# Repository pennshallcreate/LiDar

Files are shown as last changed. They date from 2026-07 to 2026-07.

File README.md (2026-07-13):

# LiDar — a budget DIY 360° 3D LiDAR scanner

A buildable, portable, USB-C-rechargeable 360° 3D scanner modeled on the
open-source [PiLiDAR](https://github.com/PiLiDAR/PiLiDAR) project: an
LDRobot 2D LiDAR spun on a stepper-driven turntable, orchestrated by a
Raspberry Pi 3 Model A+, exporting colored PLY point clouds. No camera, no panorama
stitching — just the scanning core, built to a real budget.

| | |
|---|---|
| **Cost** | $188 all-new, or $158 if you already own the Pi 3 A+ — see the budget note in [BOM.md](BOM.md) |
| **Compute** | Raspberry Pi 3 Model A+ (factory-soldered 40-pin header, dual-band Wi-Fi) |
| **Sourcing** | 100% Amazon, Prime-eligible — see [Parts.md](Parts.md) for the plain shopping list |
| **Build skill** | No soldering, no multimeter — breadboard + push-fit connectors throughout |
| **Sensor** | LDRobot LD19 (or LD06), 4500 samples/s, 0.02–12m range |
| **Runtime** | ≥2.5h worst-case, ~5.5h typical, on a single USB-C power bank charge — [proof](ARCHITECTURE.md#5-power-budget) |
| **Output** | Binary PLY point clouds, intensity-colored |
| **License** | [CC BY-NC-SA 4.0](LICENSE.md) (inherited from PiLiDAR) |

## Documentation

1. **[BOM.md](BOM.md)** — parts list, current prices, sourcing, and the
   no-solder/no-multimeter design constraints this build is built around
   (**[Parts.md](Parts.md)** has just the shopping list, no explanation)
2. **[ARCHITECTURE.md](ARCHITECTURE.md)** — wiring/pinout, motion system,
   and the power budget proving the runtime requirement
3. **[`src/`](src/)** — Python: LiDAR serial capture, stepper control,
   point-cloud assembly, PLY export, calibration
4. **[PRINTS.md](PRINTS.md)** — 3D-printed parts, dimensions, and
   parametric OpenSCAD source in [`models/`](models/)
5. **[BUILD.md](BUILD.md)** — ordered assembly and test checklist, start
   to first scan

If you're building one of these, read them in that order. If you just want
to know whether this is worth building: it's a real, working scanner for
about the price of a mid-range LiDAR sensor alone, with the tradeoffs
(anisotropic resolution, a blind cone underneath, no RGB by default)
documented rather than glossed over — see ARCHITECTURE.md's limitations
section before committing to a parts order.

## Credit

This project adapts code, wiring conventions, and the overall scan
geometry from [PiLiDAR](https://github.com/PiLiDAR/PiLiDAR) and
[PiLiDAR-Hardware](https://github.com/PiLiDAR/PiLiDAR-Hardware) by Philip
Gutjahr, CC BY-NC-SA 4.0. See [LICENSE.md](LICENSE.md) for the full
attribution and what's original vs. adapted.

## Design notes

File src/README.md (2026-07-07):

# src/

Onboard Python for the scanner (runs on the Pi itself, headless). Hardware
context is in [../ARCHITECTURE.md](../ARCHITECTURE.md); assembly and the
first-scan checklist is in [../BUILD.md](../BUILD.md) -- start there if
you're setting one of these up. This file is just a map of the code.

## Setup

```bash
python3 -m venv venv
source venv/bin/activate
pip install -r requirements.txt
```

Edit `config.json` first: set `STEPPER.DRIVER` to `"A4988"` or `"ULN2003"`
to match your build tier (BOM.md), and `LIDAR.DEVICE` to `"LD19"` or
`"LD06"`.

## Files

| File | Role |
|---|---|
| `config.json` / `config.py` | Central config: device selection, pins, scan geometry, offsets. Everything else reads from here. |
| `crc_table.json` | CRC8 lookup table for the LD06/LD19 UART protocol. |
| `lidar_driver.py` | Serial capture: reads packets, checks CRC8, decodes angle/distance/intensity, controls motor-speed PWM. |
| `stepper_driver.py` | Turntable motor control -- `A4988` (NEMA17) and `ULN2003` (28BYJ-48) classes behind one interface; `Stepper(config)` picks the right one. |
| `pointcloud.py` | 2D-per-revolution -> merged 3D point cloud, intensity colorization, binary/ASCII PLY export. Pure NumPy, no Open3D (see ARCHITECTURE.md § 2). |
| `scan.py` | Main entry point: runs a full scan and writes the PLY. `python3 scan.py --help` for options. |
| `calibrate_pwm.py` | One-time motor speed-vs-PWM calibration (produces `PWM_COEFFS` for config.json). |
| `calibrate_mechanical.py` | Fast, low-res scan for iterating on the mechanical offset constants (`Y_OFFSET`/`Z_OFFSET`/`LIDAR_OFFSET_ANGLE`). |
| `imu_driver.py` | Optional MPU6050 tilt sensor, only used if `ENABLE_IMU: true`. |
| `button_daemon.py` | Scan-trigger button listener, meant to run as a systemd service (BUILD.md). |
| `platform_utils.py` / `file_utils.py` | Small shared helpers (serial/PWM init, directory helpers). |

## Running a scan manually

```bash
python3 scan.py
```

Output goes to `scans/<timestamp>/`: the raw per-revolution pickle
(`*_lidar.pkl`) and the exported point cloud (`*.ply`).

## Attribution

Several files here are adapted from [PiLiDAR](https://github.com/PiLiDAR/PiLiDAR)
(c) Philip Gutjahr, licensed CC BY-NC-SA 4.0 -- see the per-file header
comments for which ones, and [../LICENSE.md](../LICENSE.md) for the full
license text this repository is released under as a result.

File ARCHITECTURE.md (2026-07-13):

# Architecture

System design, wiring/pinout, and the power budget proving ≥15 minutes of
continuous scan runtime. Parts referenced here are defined in
[BOM.md](BOM.md); assembly order is in [BUILD.md](BUILD.md); printed-part
geometry is in [PRINTS.md](PRINTS.md).

## 1. System overview

Like PiLiDAR, this is a **2D LiDAR spun on two axes** rather than a native 3D
LiDAR: the sensor's own motor sweeps a vertical circle at ~10 Hz, and a
stepper-driven turntable slowly sweeps that vertical circle through 180° of
azimuth over the course of a scan. The two sweeps together cover a full
sphere.

```
                         ┌───────────────┐
                         │   LD19 LiDAR   │  spins its own beam
                         │  (vertical     │  in a vertical circle
                         │   plane)       │  @ ~10 Hz
                         └───────┬───────┘
                                 │ mast
                         ┌───────┴───────┐
                         │   platter      │  rotated by a 28BYJ-48
                         │ (lazy-susan    │  through 180° over the scan
                         │  bearing)      │
                         └───────┬───────┘
                                 │
        ┌────────────────────────────────────────────┐
        │  base: Pi 3 A+, breadboard + ULN2003        │
        │  driver, buttons -- single 5V rail, no      │
        │  boost converter needed (§4.1)              │
        └────────────────────────────────────────────┘
                                 │
                         USB-C power bank
```

**Why 180°, not 360°, of turntable rotation:** one full revolution of the
LiDAR's own spin already sweeps a plane that passes through the mast axis —
i.e. it looks "forward" and "backward" (180° apart) *simultaneously*, once
per revolution. Stepping the turntable through a full 180° therefore already
sweeps that plane through every possible azimuth exactly once; going to 360°
would just re-scan the same sphere a second time. This is exactly the
geometry PiLiDAR uses (`SCAN_ANGLE: 180` in its config) and it halves scan
time for free.

**Resolution:** vertical (elevation) resolution is fixed by the LiDAR's own
sampling rate and spin speed (4500 samples/s ÷ ~10 rev/s ≈ 450 points/rev ≈
0.8°/point, native). Azimuth resolution is set by how finely the turntable
steps — see [§4](#4-motion-system) — and is comfortably finer than 0.8°, so
elevation, not azimuth, is the resolution bottleneck, same as the reference
project.

## 2. Compute: Raspberry Pi 3 Model A+

A Pi 4 (PiLiDAR's choice) is massive overkill for a LiDAR-only build with no
camera/panorama/meshing pipeline running on-device — that pipeline is the
part PiLiDAR uses the extra RAM/CPU for, and it's exactly the part we've cut.
What's left (read UART, toggle GPIO, buffer numpy arrays, write a PLY file)
comfortably fits the 3 A+'s quad-core Cortex-A53 @ 1.4 GHz and 512 MB RAM,
at well under half the Pi 4's price and power draw. The 40-pin header,
hardware PWM, and mini-UART are all identical to the Pi 4 for our purposes,
so PiLiDAR's GPIO-level driver code ports over almost unchanged (see
`src/`). Two 3 A+ perks this build actively uses: the header ships
**pre-soldered as standard** (load-bearing for the no-soldering constraint —
see BOM.md), and its dual-band 802.11ac Wi-Fi makes headless scan pull-off
faster and more reliable than a 2.4 GHz-only board in a congested
apartment-Wi-Fi environment. The full-size USB-A and HDMI ports go unused
during scanning, but they make bench debugging (keyboard, monitor, USB
serial adapter) possible without any adapters — something a Pi Zero-class
board can't offer.

**Deliberate simplification vs. PiLiDAR:** the onboard code never imports
Open3D. Point-cloud assembly is plain NumPy (coordinate transforms over a
few hundred thousand points — seconds, not minutes, on this CPU) and PLY
export is a ~30-line manual binary writer (`src/pointcloud.py`). Open3D is a
large, native-compiled dependency; avoiding it on a 512 MB board sidesteps a
real memory/build-time risk for zero loss of the required output (binary
PLY). If you want Open3D-powered visualization, ICP registration, or Poisson
meshing, PiLiDAR already documents that workflow well — run it on a laptop
against the PLY this device produces, exactly as PiLiDAR itself recommends
doing for the slow steps ("Poisson Surface Meshing... recommended to run on
PC").

## 3. GPIO pinout

All pin numbers are **BCM numbering**, all connections are push-fit Dupont
jumpers into the Pi 3 A+'s pre-soldered 40-pin header (soldered at the
factory on every 3 A+ — no soldering anywhere, see BOM.md) routed through a
breadboard. This map is carried
over from PiLiDAR unchanged where the subsystem is unchanged (LiDAR
UART/PWM, buttons) — no reason to diverge from a proven pin assignment.

| Signal | Pi GPIO (BCM) | Physical pin | Notes |
|---|---|---|---|
| LiDAR UART RX | GPIO15 (RXD0) | 10 | mini-UART (`/dev/ttyS0`); LiDAR only transmits, so TX (GPIO14) is unused. On the 3 A+ (a Bluetooth-equipped Pi) the mini-UART is disabled by default — `enable_uart=1` in `config.txt` turns it on and pins the core clock so the baud rate stays stable (BUILD.md Phase 4) |
| LiDAR motor speed (PWM) | GPIO18 (PWM0) | 12 | hardware PWM, `rpi-hardware-pwm` |
| Scan-trigger button | GPIO17 | 11 | to GND, internal pull-up, falling-edge |
| Power button | GPIO3 | 5 | hardwired wake pin; `dtoverlay=gpio-shutdown` |
| ULN2003 IN1 | GPIO26 | 37 | default build's stepper driver — see §4.1 |
| ULN2003 IN2 | GPIO19 | 35 | |
| ULN2003 IN3 | GPIO5 | 29 | |
| ULN2003 IN4 | GPIO6 | 31 | |
| IMU SDA (optional) | GPIO22 | 15 | `i2c-gpio` bus 3 — GPIO2/3 (hw I2C) are unavailable, GPIO3 is the power button |
| IMU SCL (optional) | GPIO27 | 13 | `i2c-gpio` bus 3 |
| 5V (LiDAR VCC, ULN2003 VCC, Pi power in) | 5V pins | 2, 4 | single rail — see §4.1, no boost converter in the default build |
| GND (common) | GND | 6, 9, 14, 20, 25, 30, 34, 39 | tie LiDAR GND, ULN2003 GND, button GND all to Pi GND |

**If you upgrade to the optional NEMA17 + A4988 path** (§4.2 — needs a
multimeter, not part of the default build): it reuses GPIO26/19 as
DIR/STEP, adds GPIO5/6/13 as MS1/MS2/MS3, GPIO13 (physical pin 33) being
the only pin the default ULN2003 build leaves unused. It also adds its own
3.3V (driver logic VDD, pin 1 or 17) and a boost-converter GND to the
common ground.

## 4. Motion system

### 4.1 Default build: 28BYJ-48 + ULN2003 (no multimeter, no soldering)

This is the build BUILD.md walks through. The ULN2003 board just switches
4 GPIO outputs to the motor's 4 coils in sequence (`src/stepper_driver.py`'s
`ULN2003` class) — there's no current limit to set and nothing to measure,
unlike a bipolar driver. It runs natively at 5V, so **the whole build is a
single 5V rail**: battery → Pi → (Pi's own 5V GPIO pins) → LiDAR + ULN2003.
No boost converter anywhere.

- **Direct drive, no gearbox.** Same reasoning as PiLiDAR's geared design,
  simplified: the 28BYJ-48's own internal ~64:1 gearbox already gives
  ~4096 steps/rev = 0.088°/step at its output shaft — finer than the
  LiDAR's native ~0.8° vertical resolution — and has enough torque for a
  few-hundred-gram printed mast without any additional external gearing.
  See [PRINTS.md](PRINTS.md) for the mechanical layout.
- **The lazy-susan bearing carries the load, not the motor shaft** — the
  platter sits on the hardware bearing; the motor connects via a printed
  hub that only has to transmit torque, keeping side-load off the motor's
  small internal bearings.
- **The motor's cable plugs directly into the ULN2003 board's onboard
  socket** — no crimping, no soldering, it's sold as a matched pair.
- **Torque/speed margin is real but smaller than a NEMA17's** (roughly
  1/10th the holding torque) — see [BOM.md](BOM.md#optional-upgrades-not-included-in-the-188-total)
  for when that matters and the NEMA17 upgrade path below.

### 4.2 Optional upgrade: NEMA17 + A4988 (needs a multimeter)

Not part of the default build — described here for when/if you pick up a
multimeter and want more torque/speed margin. `src/stepper_driver.py`'s
`A4988` class and `models/motor_hub_nema17.scad` already support it; set
`STEPPER.DRIVER` to `"A4988"` in `config.json` to switch.

- **Direct drive, no gearbox.** At 16× microstepping a NEMA17 alone gives
  3200 microsteps/rev = 0.1125°/step, finer than the LiDAR's native ~0.8°
  resolution, with roughly 10× the torque this load needs even ungeared —
  no need for PiLiDAR's 3D-printed planetary reduction.
- **Microstep truth table** (MS1/MS2/MS3 → resolution), standard A4988:

  | MS1 | MS2 | MS3 | Microsteps |
  |---|---|---|---|
  | Low | Low | Low | 1 (full step) |
  | High | Low | Low | 2 |
  | Low | High | Low | 4 |
  | High | High | Low | 8 |
  | High | High | High | 16 ← used |

- **Current limit (Vref) — this is the step that needs a multimeter.** Set
  the driver's onboard trimpot for **0.5 A/phase** — comfortable torque
  margin for this load without wasting battery power as heat. Formula for
  the common 0.05 Ω sense-resistor A4988 breakout (verify your board's
  sense resistor against its silkscreen/datasheet before trusting this
  number): `I_limit = V_ref × 2.5`, so `V_ref = I_limit / 2.5 = 0.2 V`.
  Measure with a multimeter between the trimpot wiper and GND, motor
  **disconnected**, before wiring it up. Get this wrong and you either
  stall the motor (limit too low) or overheat the driver (limit too high) —
  this is precisely the failure mode the default ULN2003 build has no
  equivalent of.
- **SLEEP/RESET/ENABLE.** Bridge `SLEEP` to `RESET` with a short jumper
  directly on the driver board, tie that joined pair to the driver's logic
  `VDD` (3.3V), and tie `ENABLE` (active-low) straight to `GND`.
- **VMOT (motor power) — the other multimeter step.** 12V from a boost
  converter (e.g. MT3608, 5V→12V), trimmed with its onboard pot and
  **verified with a multimeter before connecting the driver** — cheap
  boost modules can ship set to their maximum (sometimes 28V+). **Never
  run VMOT below ~8V** — the A4988's internal charge pump needs it, and
  the driver can behave unreliably below that, which is why this path
  needs a boost converter at all rather than feeding the driver straight
  off the 5V battery rail.

## 5. Power budget

**Requirement: ≥15 minutes of continuous operation with the LiDAR, stepper,
and Pi all active simultaneously (the actual worst case during a scan).**

This is for the default build: Pi + LiDAR + 28BYJ-48/ULN2003, all off one
5V rail, 10,000 mAh power bank (BOM.md). No boost converter in the loop —
one less conversion-efficiency loss to account for.

### Worst-case bound (the proof)

Deliberately pessimistic on every number, so this is a floor, not an
expectation:

| Load | Draw |
|---|---|
| Pi 3 A+ (CPU+Wi-Fi, pessimistic ceiling — measured stress figures run 0.7–0.85 A, this rounds up) | 1.00 A @ 5V = 5.00 W |
| LD19 LiDAR (datasheet current, upper end) | 0.45 A @ 5V = 2.25 W |
| 28BYJ-48/ULN2003 (datasheet worst-case combined coil current) | 0.40 A @ 5V = 2.00 W |
| **Total draw** | **9.25 W** (≈1.85 A @ 5V) |

That 1.85 A worst-case total also clears the power bank's output rating
with room to spare (typical 10,000 mAh banks deliver 2.4–3 A per port) —
use the bank's highest-rated output port, since the 3 A+'s official
recommended supply is 2.5 A.

| | |
|---|---|
| Nominal energy (10 Ah × 3.7 V) | 37.0 Wh |
| × 80% (aged-battery/cold derating) | 29.6 Wh |
| × 80% (USB boost conversion, low end — this is the power bank's own internal 3.7V-cell-to-5V-output conversion, not an external boost converter) | **23.68 Wh usable** |
| ÷ worst-case draw | 23.68 / 9.25 W |
| **Runtime floor** | **153 min (2h 33m)** |
| **Margin over the 15-min requirement** | **10.2×** |

### Typical case (practical expectation)

Real (lighter) stepper draw, fresh battery, mixed CPU/Wi-Fi load:

| | |
|---|---|
| Total typical draw | ≈6.0 W |
| Usable energy (100% capacity × 88% conversion) | 32.6 Wh |
| **Typical runtime** | **≈5h 26m** |

In practice, expect a full day of scanning (dozens of individual scans at
~1.5–2 min each, see §6) per charge, not a single 15-minute window — the
10× worst-case margin is that generous mostly because dropping the boost
converter (§4.1) removed both a conversion-efficiency loss and a
several-watt load at the same time. (The move from a Pi Zero 2 W to the
3 A+ in this revision cost roughly an hour of worst-case floor — 210 min
down to 153 min — a fair trade for the faster CPU clock, dual-band Wi-Fi,
and factory-soldered header, and still 10× more runtime than required.)

### If you add the optional NEMA17 + A4988 upgrade (§4.2)

That path reintroduces a boost converter and a heavier motor load — budget
roughly 12-15W for the stepper+driver+boost stage (current-limited to
0.5A/phase, ~80% boost efficiency) instead of the 2W above. Total draw
becomes ≈19.5-22.5W worst case, which against the same 23.68Wh usable
energy still clears the 15-minute requirement (≈63-73 min floor, 4.2-4.9×
margin) — just with noticeably less margin than the default build, and
only worth doing once you have the multimeter that path requires anyway.

## 6. Scan duration (informational, not a hard requirement)

At the default resolution (`TARGET_RES: 0.225`, which the 28BYJ-48's 4096
steps/rev turns into 682 steps of ~0.264°/step over the 180° sweep) the
LiDAR itself is the pacing element: 4500 samples/s ÷ 12 samples/package =
375 packages/s, and the scan needs
`682 steps × ~38 packages/step ≈ 25,900 packages`, i.e. **≈69 seconds** per
full 360°×180° scan. Tunable via `TARGET_RES` in `config.json`, exactly
like PiLiDAR. (The optional NEMA17 upgrade's finer 3200 steps/rev would
give ~0.1125°/step and a correspondingly longer scan at the same
`TARGET_RES` — `python3 config.py` prints the actual numbers for whatever
`config.json` currently has configured.)

## 7. Data flow

```
LD19 (UART, 230400 baud) ──▶ lidar_driver.py ──▶ raw scan buffer (numpy, per-revolution)
                                                          │
stepper_driver.py ◀── scan.py orchestrates ──────────────┤
   (steps once per revolution, records current angle)     │
                                                          ▼
                                          pointcloud.py: revolve each
                                          2D revolution by its recorded
                                          azimuth angle → merged XYZI
                                                          │
                                                          ▼
                                        intensity → viridis colormap
                                                          │
                                                          ▼
                                            binary PLY written to
                                            /scans/<timestamp>/scan.ply
```

Raw per-revolution data is also pickled to disk (`<timestamp>_lidar.pkl`,
same format as PiLiDAR) before merging, so a scan is never lost to a
crash in the merge/export step and can be re-processed later with different
offsets.

## 8. Known limitations (inherent to this scan geometry, not this budget)

- **Blind cone directly below the device.** The base/platter physically
  blocks the LiDAR's view of the ground directly underneath it — identical
  limitation to PiLiDAR and to every mast-mounted spinning-LiDAR scanner.
  Elevate the scanner (tripod, see [BUILD.md](BUILD.md)) if you need
  near-field floor coverage.
- **Anisotropic resolution.** Azimuth resolution (fine, stepper-controlled)
  and elevation resolution (coarser, fixed by the LiDAR's own spin speed)
  are not equal — same as PiLiDAR. This is a property of the "2D LiDAR on
  two axes" approach, not something a bigger budget fixes without a
  different sensor architecture entirely (e.g. a solid-state 3D LiDAR, which
  is a different price class altogether).
- **No RGB by default.** See BOM.md's optional-upgrades section.

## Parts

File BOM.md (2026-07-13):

# Bill of Materials

This scanner is a budget-hardware remix of [PiLiDAR](https://github.com/PiLiDAR/PiLiDAR)
(Raspberry Pi + LDRobot 2D LiDAR + stepper turntable → 3D point cloud). The HQ
camera / panorama-texturing half of PiLiDAR is dropped entirely — this is a
LiDAR-only scanner that exports intensity-shaded PLY point clouds.

**Builder constraints this BOM is designed around: no soldering, no
multimeter, every part on Amazon, compute fixed at a Raspberry Pi 3 Model
A+.** Every connection below
is push-fit (breadboard + Dupont jumpers + plug-in connectors) and nothing
requires measuring a voltage or current to set up — see
[the no-solder/no-multimeter design section](#design-for-no-soldering-and-no-multimeter)
for what that changed from a typical stepper-driven build. See
[Parts.md](Parts.md) for just the shopping list with no explanation.

## TL;DR

| | |
|---|---|
| **Total** | **$188 buying everything new** — or **$158 if you already own the Pi 3 A+** (see [the budget note](#the-175-cap-and-the-pi-3-a)) |
| Sourcing | 100% Amazon, Prime-eligible |
| Turntable drive | 28BYJ-48 + ULN2003 — plug-in connector, no current-limit tuning, no multimeter |
| Wiring | Solderless breadboard + Dupont jumpers throughout |
| Battery runtime, worst case / typical | see [ARCHITECTURE.md § Power budget](ARCHITECTURE.md#5-power-budget) |

## Design for no soldering and no multimeter

The stepper-driven-turntable design pattern most DIY LiDAR scanners
(including PiLiDAR itself) use is built around a NEMA17 + A4988 driver,
which needs two things this BOM specifically avoids:

1. **A4988's current limit is set with a trimpot, measured with a
   multimeter** (a wrong-by-a-lot setting can overheat the driver or
   stall the motor). No multimeter, no safe way to set it.
2. **NEMA17 needs 9-12V**, which means a boost converter between the 5V
   battery and the driver — another component whose output voltage you
   trim and verify with a multimeter before it's safe to connect to
   anything.

Both are gone from this build. Instead:

- **Motor: 28BYJ-48 + ULN2003**, not NEMA17 + A4988. The ULN2003 board
  just switches 4 GPIO signals to the motor coils directly — there's no
  current limit to set, nothing to measure, nothing to trim. It runs
  natively at 5V, so **the boost converter disappears too** — everything
  in this build (Pi, LiDAR, motor) runs off one 5V rail. This does trade
  away some torque/speed margin vs. a NEMA17 — see
  [ARCHITECTURE.md § 4](ARCHITECTURE.md#4-motion-system) for why that's a
  fine tradeoff at this load, and how to upgrade later if you ever do pick
  up a multimeter.
- **Wiring: a solderless breadboard + Dupont jumper wires**, not perfboard.
  The Pi 3 A+'s 40-pin header comes soldered from the factory (every 3 A+
  ships that way — no "WH vs W" variant trap to dodge) and takes push-on
  female Dupont wires directly — no soldering iron touches anything in
  this build. The LiDAR module's cable and the ULN2003-to-28BYJ48 connector are
  both pre-terminated plug-in connectors out of the box (see the LiDAR
  line item below for the one thing to double check when it arrives).
- **No voltage/current measurement anywhere in the build.** BUILD.md's
  power-on checklist is entirely "does it visibly move / does it print a
  reading" checks, not multimeter readings.

## Everything on Amazon

Every part below is sourced on Amazon, Prime-eligible — the whole BOM
should ship free in 1-2 days, likely in one or two boxes. This trades
away the cheaper overseas LiDAR sourcing (~$67 via a China-based reseller
like sunsky-online, 1-3 week shipping, no easy returns) for Prime speed
and Amazon's return policy — worth it on its own for the LiDAR
specifically, since a DOA sensor is much harder to diagnose without a
multimeter, and much easier to just exchange.

## Parts list — $188 ($158 without the Pi)

| Part | Price | Source | Notes |
|---|---|---|---|
| **LDRobot LD19 LiDAR** ("D300" kit: sensor + cable) | **$90** | [Amazon: WayPonDEV FHL-LD19](https://www.amazon.com/DTOF-D300-Distance-Obstacle-Education/dp/B0B1V8D36H) (also sold as [Waveshare D300](https://www.amazon.com/Waveshare-DTOF-LIDAR-LD19-Omni-Directional/dp/B0B3RWKJ1P) — compare current prices, these fluctuate more than most Amazon listings, seen $90-170) | 4500 samples/s, 0.02–12 m, 5V UART+PWM. **Check the product photos before ordering**: you want a cable ending in loose/Dupont-style female connector pins (the standard way these wire to a Pi, no tool needed). If yours instead ends in a bare-wire or unfamiliar connector, search Amazon for a small "JST to Dupont adapter cable" (~$7) — not included in the total above since most listings don't need it. LD06 is a drop-in alternative the code already supports. |
| **Raspberry Pi 3 Model A+** | **$30** (MSRP is $25; Amazon street price runs $28–35 — skip this line entirely if you already own one) | [Amazon](https://www.amazon.com/Raspberry-Pi-3-Computer-Board/dp/B07KKBCXLY) | Quad-core Cortex-A53 @ 1.4 GHz, 512 MB, dual-band Wi-Fi for headless scan pull-off, full-size USB-A + HDMI for bench debugging. The 40-pin header is **factory-soldered on every 3 A+** — the "no soldering" claim needs no special variant here, unlike the Pi Zero line. Power is micro-USB (not USB-C); official recommended supply is 2.5 A, see ARCHITECTURE.md § 5. |
| **microSD card, 32 GB, A1/A2** | **$6** | [Amazon](https://www.amazon.com/SanDisk-32GB-MicroSDHC-Memory-Card/dp/B003WGJYCY) | 16 GB would work too; 32 GB cards are cheap enough to just default to. |
| **4" square lazy-susan turntable bearing** (2-pack) | **$9** | [Amazon: 2-pack](https://www.amazon.com/Turntable-Bearings-Hardware-Rotating-Bearing/dp/B09R1S2JNB), or [single](https://www.amazon.com/Square-Inch-Susan-Turntable-Bearing/dp/B017OYZAFE), or [8-pack](https://www.amazon.com/Hardware-Rotating-Bearing-Capacity-Turntable/dp/B08CY2P8KZ) | Carries the platter's radial/thrust load — screws only, no soldering. **This is a commodity part**: any "4 inch square lazy susan turntable bearing" listing works (they're all the same ~4"/102mm zinc-plated stamped-steel design), so if the linked ones are out of stock, [search Amazon](https://www.amazon.com/s?k=4+inch+square+lazy+susan+turntable+bearing) and pick any in-stock 4" square one. Exact mounting-hole positions vary by brand, which is why the printed plates use slots + transfer-marking (PRINTS.md, BUILD.md) instead of assuming a hole pattern. |
| **28BYJ-48 + ULN2003 stepper kit** (2-set) | **$9** | [Amazon](https://www.amazon.com/KOOKYE-28BYJ-48-Stepper-ULN2003-Arduino/dp/B019TOJRC4) | Motor's cable plugs directly into the ULN2003 board's onboard socket — no crimping, no soldering. Runs natively at 5V, no current limit to set. 2-set = a spare. |
| **USB-C PD power bank, 10,000 mAh** | **$18** | [Amazon](https://www.amazon.com/Anker-Portable-Charger-Charging-Battery/dp/B0CZ9M6X8Q) | Single 5V rail powers the Pi directly; the Pi's own 5V GPIO pins in turn power the LiDAR and motor (standard practice, see ARCHITECTURE.md) — no boost converter needed anywhere in this build. |
| **Half-size solderless breadboard** (2-pack) | **$7** | [Amazon](https://www.amazon.com/s?k=half+size+solderless+breadboard+2+pack) | Central wiring hub. Half-size (not full-size) specifically because it fits the base plate's electronics zone alongside the bearing — see PRINTS.md. |
| **Tactile push-button modules** (pin-header breakout, pack) | **$6** | [Amazon](https://www.amazon.com/s?k=tactile+push+button+module+breakout+3pin) | Small PCB with the switch already on it — pushes into the breadboard or connects via Dupont wire, unlike a bare panel-mount switch which typically wants solder or crimp terminals. Need 2: scan-trigger + power. |
| **Dupont jumper wire kit** (M-M / M-F / F-F, assorted lengths) | **$7** | [Amazon](https://www.amazon.com/s?k=dupont+jumper+wire+kit+mm+mf+ff) | All signal wiring in this build is one of these three cable types. Get the multi-pack, you'll use more than you expect. |
| **M3 fastener assortment** (screws, standoffs, nuts) | **$6** | [Amazon](https://www.amazon.com/s?k=m3+screw+standoff+nut+assortment+kit) | Mechanical assembly only — a screwdriver, not a soldering iron. |

<sub>Treat every price in this document as "verified as of 2026-07-13,
reverify before ordering" — ±5–10% week-to-week retail variance is normal
for most of these parts, but the LiDAR specifically has swung $90-170
across resellers in the same search session, so compare listings before
buying it in particular. Shipping is free on all parts with Prime.</sub>

### The $175 cap and the Pi 3 A+

The original revision of this build used a $15 Pi Zero 2 WH and landed at
$173 of a $175 cap. This revision fixes the compute board as a
**Raspberry Pi 3 Model A+** instead:

- **If you already own the 3 A+** (the usual reason to specify this exact
  board), everything else totals **$158** — comfortably inside the old
  $175 cap, with real headroom for LiDAR price drift for the first time.
- **If you're buying the 3 A+ new (~$30 on Amazon), the total is $188 —
  $13 over the old $175 cap.** The [cost-reduction levers](#further-cost-reduction-levers-not-reflected-in-the-188-total)
  below claw back ~$6 at most, so an all-new build genuinely costs more
  than the Zero-2-W version did; the alternative is to keep the cap and
  buy a Pi Zero 2 WH instead, which the previous revision of these docs
  (git history) covers in full.
- Either way the LiDAR is still the swing item — it has ranged $90–170
  across Amazon listings, so compare listings before ordering it.

### Assumed already on hand (not in the totals above — check before ordering)

The parts table above is the complete set of wires and electronics *for
the scanner itself* — every electrical connection is either a Dupont
jumper from the kit or a plug-in cable included with its part. It assumes
you already own these common items; check before ordering and add any
you're missing:

- **A micro-USB cable** to power the Pi from the power bank. The Pi 3
  A+'s power port is **micro-USB, not USB-C**, and the power bank won't
  necessarily include that cable. Nearly every household has one from an
  older phone or gadget; if not, ~$5–6
  ([Amazon](https://www.amazon.com/s?k=usb+a+to+micro+usb+cable)). Prefer
  a short, thick charge-rated cable and the power bank's highest-current
  port — the 3 A+'s recommended supply is 2.5 A, and a long thin cable's
  voltage drop is the most common cause of under-voltage warnings.
- **M2.5 standoffs or small zip ties** to mount the Pi to the base
  plate's dedicated 58×49 mm hole pattern (PRINTS.md) — the Pi's own
  mounting holes are 2.75 mm, so the M3 kit's screws won't pass through
  them. Zip ties through the same holes work fine if you don't have M2.5
  hardware.
- **A way to get the microSD card into your computer** for the one-time
  OS flash — an SD slot (the SanDisk card usually ships with a full-size
  SD adapter) or a ~$7 USB reader
  ([Amazon](https://www.amazon.com/s?k=usb+sd+card+reader)).
- **Zip ties and a hook-and-loop strap or bungee** (wire routing along
  the mast, battery mounting — BUILD.md's tools list).
- Phillips screwdriver and a small hex/Allen key.

## Optional upgrades (not included in the $188 total)

Out of scope per the brief ("HQ camera / RGB coloring is optional — drop
it to hit budget") but documented as fork points since the code has hooks
for them.

| Upgrade | Adds | Cost | What it buys |
|---|---|---|---|
| **IMU (GY-521 / MPU6050)** | +$7 ([Amazon](https://www.amazon.com/HiLetgo-MPU-6050-Accelerometer-Gyroscope-Converter/dp/B078SS8NQV)) | I2C tilt sensor, pin-header — same solderless Dupont-wire connection as everything else here | Auto-levels the point cloud if the tripod/ground isn't perfectly level. `src/imu_driver.py` supports it; set `ENABLE_IMU: true` in `config.json`. |
| **Basic RGB coloring** | +$20–30 (Pi Camera Module 3, [Amazon](https://www.amazon.com/s?k=raspberry+pi+camera+module+3)) | Per-step photo, angular color lookup | PiLiDAR's full build uses a $60 HQ camera + M12 lens + Hugin panorama stitching. Out of scope here; a cheap Pi Camera Module taking one photo per stepper stop gets *rough* RGB instead of intensity-grayscale. Not implemented in `src/` — noted as a fork point. |
| **NEMA17 + A4988 motor upgrade** | net +$10ish, **requires acquiring a multimeter** | More torque/speed margin (~10× holding torque) | The "standard" DIY-scanner drive train this BOM deliberately avoids — see the design section above. `src/stepper_driver.py`'s `A4988` class and `models/motor_hub_nema17.scad` already support this if you ever pick up a multimeter; [ARCHITECTURE.md § 4.2](ARCHITECTURE.md#42-optional-upgrade-nema17--a4988-needs-a-multimeter) and BUILD.md's appendix have the setup steps. Not recommended as a first build without one. |
| **STL-27L sensor instead of LD19** | +$90–95 | 21,600 samples/s vs 4,500 (~5×), same 12 m range | Meaningfully denser clouds, but the sensor alone costs more than half this entire build. Only makes sense if you've abandoned the budget constraint entirely. |

## Further cost-reduction levers (not reflected in the $188 total)

If the LiDAR listing you find runs above $90 and you need to claw back
some budget:

- **Skip the spare 28BYJ-48/ULN2003 set**: −$4 or so. Fine if you're
  confident in your wiring.
- **16 GB instead of 32 GB microSD**: −$1 to −$2.
- **Shop around between the two Amazon LiDAR listings above** (and any
  other "D300"/"FHL-LD19" listings you find) — this single line item has
  the widest price spread of anything in the BOM, so a few minutes of
  comparing could easily be worth more than every other lever combined.

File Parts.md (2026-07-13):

# Parts

Shopping list only — for prices, sourcing notes, and design rationale see
[BOM.md](BOM.md). All parts on Amazon. Total: **$188** — or **$158 if you
already own the Raspberry Pi 3 A+** (see BOM.md's budget note).

| Part | Price | Link |
|---|---|---|
| LDRobot LD19 LiDAR ("D300" kit) | $90 | [Amazon](https://www.amazon.com/DTOF-D300-Distance-Obstacle-Education/dp/B0B1V8D36H) |
| Raspberry Pi 3 Model A+ (skip if you already own one) | $30 | [Amazon](https://www.amazon.com/Raspberry-Pi-3-Computer-Board/dp/B07KKBCXLY) |
| microSD card, 32 GB, A1/A2 | $6 | [Amazon](https://www.amazon.com/SanDisk-32GB-MicroSDHC-Memory-Card/dp/B003WGJYCY) |
| 4" square lazy-susan turntable bearing (2-pack) | $9 | [Amazon](https://www.amazon.com/Turntable-Bearings-Hardware-Rotating-Bearing/dp/B09R1S2JNB) — commodity part, [any in-stock 4" square one works](https://www.amazon.com/s?k=4+inch+square+lazy+susan+turntable+bearing) |
| 28BYJ-48 + ULN2003 stepper kit (2-set) | $9 | [Amazon](https://www.amazon.com/KOOKYE-28BYJ-48-Stepper-ULN2003-Arduino/dp/B019TOJRC4) |
| USB-C PD power bank, 10,000 mAh | $18 | [Amazon](https://www.amazon.com/Anker-Portable-Charger-Charging-Battery/dp/B0CZ9M6X8Q) |
| Half-size solderless breadboard (2-pack) | $7 | [Amazon](https://www.amazon.com/s?k=half+size+solderless+breadboard+2+pack) |
| Tactile push-button modules (pack) | $6 | [Amazon](https://www.amazon.com/s?k=tactile+push+button+module+breakout+3pin) |
| Dupont jumper wire kit (M-M / M-F / F-F) | $7 | [Amazon](https://www.amazon.com/s?k=dupont+jumper+wire+kit+mm+mf+ff) |
| M3 fastener assortment (screws, standoffs, nuts) | $6 | [Amazon](https://www.amazon.com/s?k=m3+screw+standoff+nut+assortment+kit) |

## Assumed already on hand (not in the totals above — check before ordering)

| Item | If you don't have one |
|---|---|
| **Micro-USB cable** (power bank → Pi; the Pi 3 A+'s power port is micro-USB, *not* USB-C — use a short, thick charge-rated one) | ~$5–6, [Amazon](https://www.amazon.com/s?k=usb+a+to+micro+usb+cable) |
| **M2.5 standoffs or small zip ties** (Pi → base plate; the Pi's 2.75 mm mounting holes are too small for the M3 kit) | ~$7, [Amazon](https://www.amazon.com/s?k=m2.5+standoff+kit), or zip-tie it |
| SD-card slot or USB reader on your computer (one-time OS flash; the SanDisk card usually includes a full-size SD adapter) | ~$7, [Amazon](https://www.amazon.com/s?k=usb+sd+card+reader) |
| Zip ties + a hook-and-loop strap or bungee (wire routing, battery mounting) | a few $, any store |
| Phillips screwdriver + small hex/Allen key | — |

With those on hand, the table above is the complete set of wires and
electronics — every electrical connection in the build is either a Dupont
jumper from the kit or a plug-in cable included with its part. The one
exception to verify on arrival: the LiDAR's cable end (see BOM.md's LiDAR
row — a ~$7 JST-to-Dupont adapter is the fallback if it isn't
Dupont-style).

## Optional add-ons (not in the $188 total)

| Part | Price | Link |
|---|---|---|
| GY-521 / MPU6050 IMU | $7 | [Amazon](https://www.amazon.com/HiLetgo-MPU-6050-Accelerometer-Gyroscope-Converter/dp/B078SS8NQV) |
| Pi Camera Module 3 | $20–30 | [Amazon](https://www.amazon.com/s?k=raspberry+pi+camera+module+3) |

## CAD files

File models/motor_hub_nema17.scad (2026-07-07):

// NEMA17 shaft hub (Recommended tier) -- see PRINTS.md.
// Clamps onto the NEMA17's 5mm D-shaft via a radial M3 set screw, bolts
// to the platter's underside via 3x M3 on the hub_bolt_circle_d pattern
// (must match platter.scad). Print with the bore axis vertical, no
// supports needed. PETG recommended -- this part sees the most stress
// in the whole build (all drive torque passes through it).
$fn = 64;

hub_d = 30;   // bumped from 25 -- with a 20mm bolt circle + 3.4mm holes, 25 left only ~0.8mm wall at the hub edge
hub_h = 15;

shaft_bore_d = 5.2;    // NEMA17 shaft is 5mm nominal -- +0.2mm print fit allowance
setscrew_d = 3.2;      // M3 set screw, thread-formed directly into the print
                       // (or tap M3 / use a threaded insert)

bolt_circle_d = 20;    // MUST match platter.scad's hub_bolt_circle_d
bolt_hole_d = 3.4;
bolt_angles = [90, 210, 330];  // MUST match platter.scad's hub_angles

difference() {
    cylinder(d = hub_d, h = hub_h);

    translate([0, 0, -1]) cylinder(d = shaft_bore_d, h = hub_h + 2);

    // radial set screw, midway up the bore
    translate([0, 0, hub_h / 2])
        rotate([0, 90, 0])
            cylinder(d = setscrew_d, h = hub_d, center = true);

    translate([0, 0, hub_h - 4])
        for (a = bolt_angles)
            rotate([0, 0, a])
                translate([bolt_circle_d / 2, 0, 0])
                    cylinder(d = bolt_hole_d, h = 10);
}

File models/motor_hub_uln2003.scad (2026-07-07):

// 28BYJ-48 shaft hub (Budget tier) -- see PRINTS.md.
// IMPORTANT: many 28BYJ-48 kits ship with a small plastic coupler/gear
// already pressed onto the output shaft. Either remove it and bore this
// hub for the bare ~5mm D-shaft (default below), or measure that
// coupler's OD and change shaft_bore_d to clamp onto it instead -- check
// your kit before printing. Bolts to the platter via the same 3x M3
// pattern as motor_hub_nema17.scad (must match platter.scad).
// Print with the bore axis vertical, no supports needed.
$fn = 64;

hub_d = 30;
hub_h = 12;   // 28BYJ-48's output shaft is shorter than a NEMA17's -- less engagement needed/available

shaft_bore_d = 5.2;    // verify against your kit -- see note above
setscrew_d = 3.2;

bolt_circle_d = 20;    // MUST match platter.scad's hub_bolt_circle_d
bolt_hole_d = 3.4;
bolt_angles = [90, 210, 330];  // MUST match platter.scad's hub_angles

difference() {
    cylinder(d = hub_d, h = hub_h);

    translate([0, 0, -1]) cylinder(d = shaft_bore_d, h = hub_h + 2);

    translate([0, 0, hub_h / 2])
        rotate([0, 90, 0])
            cylinder(d = setscrew_d, h = hub_d, center = true);

    translate([0, 0, hub_h - 4])
        for (a = bolt_angles)
            rotate([0, 0, a])
                translate([bolt_circle_d / 2, 0, 0])
                    cylinder(d = bolt_hole_d, h = 10);
}

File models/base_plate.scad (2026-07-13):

// Base plate -- see PRINTS.md for the full dimensioned spec.
// Print flat, no supports needed. PETG or PLA, 3-4 walls, 25% infill.
$fn = 64;

// ---- key parameters (edit to match YOUR parts before printing) ----------
plate_x = 220;
plate_y = 150;
plate_t = 4;
corner_r = 8;

bearing_center = [70, 75];       // rotation axis -- also motor + platter center
bearing_bolt_circle_d = 85;      // verify against your actual bearing, see PRINTS.md
bearing_slot_w = 4;
bearing_slot_l = 12;
center_bore_d = 30;              // motor shaft + wiring pass-through

nema17_pattern = 31.04;          // standard NEMA17 mounting square
uln2003_spacing = 35;            // 28BYJ-48 ear-to-ear spacing (verify against your unit)
motor_hole_d = 3.4;              // M3 clearance

tripod_center = [110, 75];
tripod_boss_d = 20;
tripod_pilot_d = 9.6;            // standard 1/4"-20 heat-set insert pilot -- verify against yours
tripod_boss_h = 10;

foot_positions = [[15, 15], [15, 135], [205, 15], [205, 135]];  // 4 corners, clear of the grid (see clearance note in PRINTS.md)
foot_d = 14;
foot_h = 40;                     // clears the NEMA17 body hanging underneath

button_holes = [[150, 8], [180, 8]];  // 8mm margin from edge -- was 0 (on the edge), which cut open notches instead of round holes
button_d = 12;

// electronics mounting grid (generic -- fits driver/boost/terminal block
// regardless of exact layout, see PRINTS.md rationale)
grid_x0 = 135; grid_x1 = 190;
grid_y0 = 35;  grid_y1 = 115;  // kept well clear (>=20mm) of feet/buttons/straps/edges -- see PRINTS.md clearance note
grid_step = 20;
grid_hole_d = 3.4;

// dedicated Raspberry Pi 3 A+ mounting pattern (58 x 49 mm, the published
// Pi/HAT standard -- the compute board is fixed now, so it gets real holes).
// Board is 65 x 56; placed in the upper part of the electronics area,
// leaving the strip below it (y < ~80) for the breadboard + ULN2003.
// The Pi's holes are 2.75mm: use M2.5 standoffs or zip ties, NOT the M3 kit.
pi3a_center = [165, 108];
pi3a_dx = 58;
pi3a_dy = 49;
pi3a_hole_d = 2.8;

// battery-strap slots (power bank is strapped on, not enclosed -- see PRINTS.md)
strap_slots = [[130, 8], [130, 142]];
strap_slot_w = 20;
strap_slot_h = 3;

// ---------------------------------------------------------------------

module rounded_rect(x, y, r) {
    hull() {
        for (dx = [r, x - r])
            for (dy = [r, y - r])
                translate([dx, dy]) circle(r = r);
    }
}

module bearing_slots(center, bolt_circle_d, slot_w, slot_l) {
    for (a = [45, 135, 225, 315])
        translate(center)
            rotate([0, 0, a])
                translate([bolt_circle_d / 2, 0])
                    square([slot_l, slot_w], center = true);
}

module nema17_holes(center, pattern, hole_d) {
    for (dx = [-pattern / 2, pattern / 2])
        for (dy = [-pattern / 2, pattern / 2])
            translate(center + [dx, dy])
                circle(d = hole_d);
}

module uln2003_holes(center, spacing, hole_d) {
    for (dx = [-spacing / 2, spacing / 2])
        translate(center + [dx, 0])
            circle(d = hole_d);
}

module pi3a_holes(center, dx, dy, hole_d) {
    for (sx = [-dx / 2, dx / 2])
        for (sy = [-dy / 2, dy / 2])
            translate(center + [sx, sy])
                circle(d = hole_d);
}

module mounting_grid(x0, x1, y0, y1, step, hole_d) {
    nx = floor((x1 - x0) / step);
    ny = floor((y1 - y0) / step);
    for (i = [0:nx])
        for (j = [0:ny])
            translate([x0 + i * step, y0 + j * step])
                circle(d = hole_d);
}

module base_plate_2d() {
    difference() {
        rounded_rect(plate_x, plate_y, corner_r);

        translate(bearing_center) circle(d = center_bore_d);
        bearing_slots(bearing_center, bearing_bolt_circle_d, bearing_slot_w, bearing_slot_l);
        nema17_holes(bearing_center, nema17_pattern, motor_hole_d);
        uln2003_holes(bearing_center, uln2003_spacing, motor_hole_d);

        mounting_grid(grid_x0, grid_x1, grid_y0, grid_y1, grid_step, grid_hole_d);
        pi3a_holes(pi3a_center, pi3a_dx, pi3a_dy, pi3a_hole_d);

        for (p = button_holes) translate(p) circle(d = button_d);
        for (p = strap_slots) translate(p) square([strap_slot_w, strap_slot_h], center = true);
    }
}

module tripod_boss() {
    overlap = 0.5; // ensure a real overlap with the plate, not a coincident face
    translate([tripod_center[0], tripod_center[1], -tripod_boss_h])
        difference() {
            cylinder(d = tripod_boss_d, h = tripod_boss_h + overlap);
            translate([0, 0, -1]) cylinder(d = tripod_pilot_d, h = tripod_boss_h + 2 + overlap);
        }
}

module feet() {
    overlap = 0.5; // ditto
    for (p = foot_positions)
        translate([p[0], p[1], -foot_h])
            cylinder(d = foot_d, h = foot_h + overlap);
}

union() {
    linear_extrude(height = plate_t) base_plate_2d();
    tripod_boss();
    feet();
}

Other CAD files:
models/lidar_mount.scad
models/mast.scad
models/platter.scad

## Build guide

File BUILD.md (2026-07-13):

# Build Guide

Ordered assembly and test checklist for the default build: 28BYJ-48/ULN2003
motor, breadboard wiring, **no soldering and no multimeter required
anywhere in this document.** Read [BOM.md](BOM.md) (parts),
[ARCHITECTURE.md](ARCHITECTURE.md) (wiring/pinout/power) and
[PRINTS.md](PRINTS.md) (printed parts) first — this doc assumes you have
all the parts in hand and the printed parts already printed.

If you later pick up a multimeter and want to upgrade to the NEMA17 +
A4988 drive train for more torque/speed margin, that's a separate
appendix at the end of this doc, not part of the steps below.

## Tools you'll need

- Phillips screwdriver (M3 hardware)
- Small hex/Allen key matching your motor hub's set screw
- Zip ties (wire routing along the mast), hook-and-loop strap or bungee
  (battery)
- A computer with an SD card reader + [Raspberry Pi Imager](https://www.raspberrypi.com/software/)
- Phone/laptop to view the exported PLY (MeshLab, CloudCompare, or any
  point-cloud viewer) for the calibration and final-scan checks

Notably absent: soldering iron, multimeter. Every electrical connection in
this build is a push-fit Dupont wire or a plug-in connector — see BOM.md's
design section for why.

---

## Phase 1 — Print & prepare parts

- [ ] Print all 6 parts from [`models/`](models/) per [PRINTS.md](PRINTS.md)'s
      settings table (you only need `motor_hub_uln2003.scad`, not
      `motor_hub_nema17.scad`, unless you're doing the appendix upgrade)
- [ ] Test-fit the lazy-susan bearing against the base plate and platter's
      slot pattern *before* attaching anything else — the slots are
      deliberately tolerant of exact hole spacing, but confirm your screws
      actually land in material, not thin air
- [ ] Deburr the center bore and all M3 holes (a 3.5-4mm drill bit twisted
      by hand through each hole removes first-layer elephant's-foot
      without a drill press)
- [ ] If using a 1/4"-20 heat-set insert for the tripod mount: these
      normally install with a soldering iron on low heat, which this build
      otherwise avoids entirely. If you don't have one, skip the insert —
      thread a screw directly into the printed boss instead (works fine in
      PETG/PLA for occasional tripod mounting; it just won't take
      re-threading forever), or leave the tripod mount unused and scan
      from a flat surface.

## Phase 2 — Mechanical assembly

- [ ] Screw the lazy-susan bearing's fixed leaf to the base plate (through
      the slots)
- [ ] Screw the bearing's rotating leaf to the platter
- [ ] Set the 28BYJ-48 aside for now — wire it in Phase 3 before final
      mounting, its connector is much easier to reach before the platter
      is on top of it
- [ ] Press the motor hub (`motor_hub_uln2003.scad`) onto the motor's
      output shaft, snug the set screw onto the shaft's flat (or the
      pressed-on coupler — check which your kit has, PRINTS.md § 6) —
      don't fully tighten yet, you'll want to adjust hub height once the
      motor is mounted
- [ ] Mount the motor to the base plate's underside (2 screws), shaft
      pointing up through the center bore
- [ ] Bolt the hub to the platter's underside (3 screws), lower the
      platter onto the bearing, and adjust the motor's position/hub height
      so the shaft engages the hub without binding or side-loading the
      bearing — this is a "loose torque coupling," the bearing carries the
      weight, not the motor shaft (ARCHITECTURE.md § 4.1)
- [ ] Now fully tighten the hub set screw
- [ ] Confirm the motor body clears the ground with the base plate's feet
      resting on a flat surface
- [ ] Bolt the mast's bottom flange to the platter
- [ ] Bolt the LiDAR mount bracket to the mast's top flange
- [ ] Bolt the LD06/LD19 to the bracket (double-check the 3-hole spacing
      matches your unit first — PRINTS.md flags this as unverified)
- [ ] **Sanity-check sensor orientation now, before wiring**: the sensor's
      spin axis should be horizontal (its flat mounting face vertical, its
      round housing facing outward) — see ARCHITECTURE.md § 1's diagram.
      A sensor mounted flat like in a robot vacuum will not produce a
      usable scan.

## Phase 3 — Wiring (all push-fit, no soldering)

Follow [ARCHITECTURE.md's pinout table](ARCHITECTURE.md#3-gpio-pinout)
exactly. Everything below is a female Dupont wire pushed onto a Pi header
pin at one end and either a breadboard row or a component's own pin/socket
at the other — nothing here is soldered or crimped.

- [ ] Mount the Pi 3 A+ to the base plate's dedicated 58×49mm hole
      pattern (PRINTS.md § 1) — M2.5 standoffs if you have them, small
      zip ties through the same holes if you don't (the M3 kit's screws
      are too big for the Pi's 2.75mm mounting holes). Orient it with the
      40-pin header facing the breadboard area.
- [ ] Seat the breadboard(s) in the base plate's open electronics area
      (adhesive backing or a strip of hook-and-loop tape — see PRINTS.md)
- [ ] Wire the LiDAR's cable: check the connector end first (see BOM.md's
      LiDAR row) — if it's Dupont-style female sockets, push them straight
      onto male jumper wires or Pi header pins; if not, use the JST-to-Dupont
      adapter cable. UART TX → Pi GPIO15 (RX), PWM/MOTOCTL → Pi GPIO18,
      GND → Pi GND, VCC → Pi 5V. **Do not cross TX/RX** — the sensor only
      transmits, so its TX goes to the Pi's RX; there is no wire from any
      Pi TX pin to the sensor.
- [ ] Wire the ULN2003 board: IN1-IN4 → GPIO26/19/5/6, VCC → 5V, GND → GND
      (all from the same rail as the Pi — ARCHITECTURE.md § 4.1's single-rail
      design, nothing to trim or measure)
- [ ] Plug the 28BYJ-48's cable into the ULN2003 board's onboard socket —
      it's keyed, it only goes in one way
- [ ] Push the two button modules' pins into the breadboard, wire one
      between GPIO17 and GND (scan-trigger) and the other between GPIO3
      and GND (power) — both use the Pi's internal pull-ups, no resistor
      needed
- [ ] Optional IMU: SDA→GPIO22, SCL→GPIO27, VCC→3.3V, GND→GND
- [ ] Route all wiring along the mast with zip ties, leaving enough slack
      at the platter/base joint for the full 180° sweep without snagging
- [ ] Zip-tie/strap the power bank to the base plate's strap slots
- [ ] Double-check every connection against the pinout table by eye before
      powering on — this is the "no multimeter" build's substitute for a
      continuity check. Look for: any wire on the wrong pin, any loose
      push-fit connection, and that nothing is bridging two adjacent
      breadboard rows that shouldn't be connected.

## Phase 4 — Software setup

- [ ] Flash Raspberry Pi OS Lite (64-bit, Bookworm or later) to the
      microSD with Raspberry Pi Imager; in the imager's advanced options,
      set hostname, enable SSH, and set your Wi-Fi credentials so you can
      reach it headless
- [ ] Boot the Pi, SSH in, then `sudo raspi-config` or edit
      `/boot/firmware/config.txt` directly to add:
      ```
      enable_uart=1
      dtoverlay=gpio-shutdown
      dtoverlay=pwm-2chan
      ```
      (`enable_uart=1` turns on the mini-UART on GPIO14/15 — it's
      **disabled by default on Bluetooth-equipped Pis like the 3 A+**,
      and this setting also pins the core clock so the UART baud rate
      stays stable; without it `/dev/ttyS0` won't exist. The
      `gpio-shutdown` overlay makes GPIO3 a wake/shutdown button per
      BOM.md's power button; `pwm-2chan` enables hardware PWM on
      GPIO18/19 for the LiDAR motor-speed control —
      `src/platform_utils.py` falls back to software PWM automatically if
      you skip this, just with more jitter)
- [ ] If using the optional IMU, also add:
      ```
      dtparam=i2c_arm=off
      dtoverlay=i2c-gpio,bus=3,i2c_gpio_delay_us=1,i2c_gpio_sda=22,i2c_gpio_scl=27
      ```
- [ ] Grant serial port permissions permanently via udev rule (avoids the
      "chmod every boot" hack):
      ```
      sudo sh -c 'echo KERNEL==\"ttyS0\",GROUP=\"dialout\",MODE=\"0660\" > /etc/udev/rules.d/50-ttyS0.rules'
      sudo usermod -a -G dialout $USER
      sudo udevadm control --reload-rules
      sudo reboot
      ```
- [ ] Remove the RPi.GPIO sysfs backend and install the lgpio-backed
      replacement (Bookworm removed the old interface — see
      ARCHITECTURE.md/`src/requirements.txt`):
      ```
      sudo apt remove -y python3-rpi.gpio
      sudo apt update
      ```
- [ ] Clone this repo onto the Pi, then:
      ```
      cd LiDar/src
      python3 -m venv venv --system-site-packages
      source venv/bin/activate
      pip install -r requirements.txt
      ```
- [ ] Check `src/config.json`: `STEPPER.DRIVER` should already be
      `"ULN2003"` (the default) and `LIDAR.DEVICE` should match your sensor
      (`"LD19"` or `"LD06"`)
- [ ] Install the scan-button daemon as a systemd service:
      ```
      sudo tee /etc/systemd/system/lidar-scanner.service <<'EOF'
      [Unit]
      Description=LiDAR Scanner Button Daemon
      After=network.target

      [Service]
      Type=simple
      User=pi
      WorkingDirectory=/home/pi/LiDar/src
      Environment=LG_WD=/tmp
      ExecStart=/home/pi/LiDar/src/venv/bin/python3 /home/pi/LiDar/src/button_daemon.py
      Restart=on-failure

      [Install]
      WantedBy=multi-user.target
      EOF
      sudo systemctl daemon-reload
      sudo systemctl enable --now lidar-scanner.service
      sudo systemctl status lidar-scanner.service
      ```
      (adjust the `pi`/`/home/pi` paths if your username or clone location
      differ)

## Phase 5 — Power-on checks (before the first real scan)

Do these *in order* — each one only makes sense if the previous one
passed. None of these need a multimeter; they're all "does it visibly do
the right thing" checks.

- [ ] Power the Pi alone (motor and LiDAR still unplugged from their
      signal pins, only Pi 5V connected) — confirm it boots and you can
      SSH in
- [ ] Plug in the LiDAR only. Run `python3 src/lidar_driver.py` — you
      should see it print a rotation speed reading within a couple
      seconds. If `/dev/ttyS0` doesn't exist at all: `enable_uart=1` is
      missing from `/boot/firmware/config.txt` (Phase 4). If it exists
      but nothing happens: check the UART wiring isn't crossed, check
      `ls -l /dev/ttyS0` shows `dialout` group access, check
      `dtoverlay=pwm-2chan` is actually in `/boot/firmware/config.txt`
- [ ] Plug in the motor/ULN2003 only. Run `python3 src/stepper_driver.py`
      — the turntable should visibly rotate a few degrees and back. If it
      doesn't move at all: recheck the IN1-IN4 wiring order and that the
      motor's connector is fully seated in the ULN2003 socket. If it
      vibrates or judders instead of turning smoothly: two of the IN1-IN4
      wires are likely swapped — swap any adjacent pair and retry.
- [ ] Press the scan button once with both connected. Confirm
      `systemctl status lidar-scanner` shows it launched `scan.py`, and
      that a new folder appears under `src/scans/`.

## Phase 6 — Calibration

- [ ] **PWM speed calibration** (only if you enabled hardware PWM — skip
      if you never enabled `pwm-2chan`, or if your board already spins at
      a reasonable default rate): run `python3 src/calibrate_pwm.py`,
      paste the printed `PWM_COEFFS` into `config.json`
- [ ] **Mechanical offset calibration**: run
      `python3 src/calibrate_mechanical.py --angle 90 --res 1.0` pointed at
      a real corner of a room (two walls meeting at 90°, ideally with a
      visible floor/wall line). Open the resulting PLY. If the walls look
      doubled, curved, or non-perpendicular:
      - measure your actual sensor offset from the mast axis (the physical
        dimension the `lidar_mount.scad` bracket sets, PRINTS.md § 4) and
        update `Y_OFFSET`/`Z_OFFSET` in `config.json`
      - if the walls are straight but not perpendicular, adjust
        `LIDAR_OFFSET_ANGLE` in small (~0.5°) steps
      - re-run and re-check until walls read flat and square. This is the
        same hand-fitting process PiLiDAR's own reference build uses —
        there's no shortcut, but it only needs doing once per assembled
        unit.

## Phase 7 — First full scan + acceptance checklist

- [ ] Run `python3 src/scan.py` (or press the physical button) in a room
      with some clutter/furniture (flat empty rooms are a bad first test —
      you can't tell noise from a genuinely flat wall)
- [ ] Confirm the scan completes without a `[WARNING] merged point cloud
      is empty` message and without the process dying partway through
- [ ] Confirm `scans/<timestamp>/<timestamp>.ply` exists and its file size
      is more than a few KB (an empty/near-empty PLY is a red flag, not a
      quiet room)
- [ ] Open the PLY in MeshLab/CloudCompare/any viewer:
  - [ ] Walls and furniture are recognizable, not a shapeless blob
  - [ ] The colored (intensity-gradient) point cloud shows visible
        structure, not uniform noise
  - [ ] No obvious double-imaging (the same wall showing up twice, offset
        — usually a mechanical-offset calibration issue, back to Phase 6)
- [ ] Time a full scan and confirm it's in the ballpark of
      [ARCHITECTURE.md § 6](ARCHITECTURE.md#6-scan-duration-informational-not-a-hard-requirement)'s
      ~69 second estimate at default settings — a scan taking 5-10x longer
      usually means the LiDAR's actual rotation speed is off from
      `TARGET_SPEED`, back to the PWM calibration
- [ ] Battery runtime spot-check: fully charge the power bank, run 3-4
      back-to-back scans with only a few seconds between them, confirm the
      bank isn't reporting a critically-low charge — this is a sanity
      check on [ARCHITECTURE.md's power budget](ARCHITECTURE.md#5-power-budget),
      not a substitute for it

## Troubleshooting quick reference

| Symptom | Likely cause |
|---|---|
| `RuntimeError: Failed to add edge detection` on button daemon start | Old `RPi.GPIO` sysfs backend still installed — see Phase 4's `apt remove python3-rpi.gpio` step |
| `/dev/ttyS0` doesn't exist | `enable_uart=1` missing from `/boot/firmware/config.txt` — the 3 A+'s mini-UART is off by default (Phase 4) |
| LiDAR never syncs / constant CRC warnings | Wrong baud rate in `config.json` for your device, or a bad/loose UART connection |
| Random under-voltage warnings / lightning-bolt icon | Long or thin micro-USB power cable — use a short charge-rated cable and the power bank's highest-current port (the 3 A+ wants a 2.5 A-capable supply) |
| Motor vibrates/judders but doesn't turn | Two of the IN1-IN4 wires are swapped — check the order against ARCHITECTURE.md's pinout table |
| Motor turns but skips steps under load | 28BYJ-48 is near its torque limit — check nothing is binding in the bearing/hub coupling before assuming the motor is faulty |
| Scan runs but PLY is empty | Check `lidar.z_angles` isn't empty in a manual `scan.py` run — usually means the stepper callback never fired, i.e. `max_packages` was reached before one full `out_len` revolution completed (a resolution/config mismatch) |
| Point cloud is a flat line or plane, not 3D | Sensor is mounted with its spin axis vertical instead of horizontal — recheck Phase 2's orientation sanity check |
| Everything works but drifts/leans after a few scans | PLA mast creep under load — see PRINTS.md's material recommendation, reprint the mast in PETG |

---

## Appendix: upgrading to NEMA17 + A4988 (needs a multimeter)

Only do this once you have a multimeter — the whole point of the default
build above is that you don't need one. See
[ARCHITECTURE.md § 4.2](ARCHITECTURE.md#42-optional-upgrade-nema17--a4988-needs-a-multimeter)
for the full wiring/tuning detail; this is just how it slots into the
phases above:

- **Phase 1**: print `motor_hub_nema17.scad` instead of (or in addition
  to) `motor_hub_uln2003.scad`
- **Phase 2**: same mechanical steps, but the NEMA17 mounts with 4 screws
  instead of 2
- **Phase 3**: wire the A4988 instead of the ULN2003 (DIR→GPIO26,
  STEP→GPIO19, MS1/MS2/MS3→GPIO5/6/13, logic VDD→3.3V), bridge SLEEP to
  RESET, tie ENABLE to GND. Add a boost converter: power it alone first
  and **trim its output to 12.0V with a multimeter** before connecting it
  to anything. With the motor still disconnected, power the A4988 and
  **set its current-limit trimpot for 0.5V at Vref**, verified with the
  multimeter. Only then connect the NEMA17's coil wires.
- **Phase 4**: set `STEPPER.DRIVER` to `"A4988"` in `config.json`
- **Phase 5**: the stepper power-on check becomes "if it doesn't move,
  recheck SLEEP/RESET and ENABLE-to-GND wiring; if it skips/stalls, your
  Vref current limit is likely too low"

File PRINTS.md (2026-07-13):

# 3D-Printed Parts

Six parts, parametric OpenSCAD source in [`models/`](models/) (open with the
free [OpenSCAD](https://openscad.org/) app to tweak dimensions or export
STL). Every file was rendered and checked in this repo's CI-equivalent
process (`openscad --render`, exported to STL, visually inspected for
overlapping/colliding holes) — see the PNG preview next to each part below.
That verification caught and fixed two real layout bugs during design (a
mounting hole placed exactly on the plate edge, and a foot standoff whose
footprint silently overlapped a grid hole); the numbers below are the
corrected, checked versions, not a first draft.

**What's *not* verified**: the exact hole spacing on the LD06/LD19's own
mounting face and on your specific lazy-susan bearing. Those two figures are
common/representative values from general knowledge, not measured off a
datasheet or a part in hand — see the callouts below. Everything else
(bolt patterns between our own printed parts, standard NEMA17 dimensions,
M3 clearances) is either self-consistent by construction or a fixed
mechanical standard, so it's solid.

## Design approach

Rather than adapting PiLiDAR-Hardware's exact CAD files (their planetary
gearbox + Pi4-sized enclosure geometry doesn't bolt up to this build's
different motor/bearing choices — see [BOM.md](BOM.md) for why), these six
parts are a from-scratch, simpler mechanical layout sized around this
build's parts:

- **No gearbox.** Direct-drive 28BYJ-48 (or, as an upgrade, NEMA17)
  instead of PiLiDAR's 3D-printed planetary reduction — see
  [ARCHITECTURE.md § 4](ARCHITECTURE.md#4-motion-system) for the
  resolution math showing this doesn't cost any azimuth precision.
- **A hardware lazy-susan bearing carries the load**, not the motor shaft
  or a printed thrust surface — cheap, and it's the difference between a
  turntable that's rigid for years and one that wears loose in a month.
- **The battery is strapped on, not enclosed.** A flat strap area (two
  slots, any hook-and-loop strap or bungee) fits whatever power bank you
  have or swap in later, rather than locking in one exact size.
- **A dedicated Raspberry Pi 3 A+ hole pattern plus a generic M3 grid.**
  The compute board is now fixed as a Pi 3 A+, and its 58×49mm mounting
  pattern is a published standard (shared with every HAT), so the base
  plate carries real holes for it — ⌀2.8mm, for M2.5 standoffs or zip
  ties, since the Pi's own holes are 2.75mm and won't pass the M3 kit's
  screws. Everything else (driver board, buttons) keeps the generic 20mm
  grid of M3 clearance holes: those boards' footprints vary by exactly
  which listing you bought, so zip-tie or M3-standoff whatever you
  actually have. The breadboard(s) sit in the same area (adhesive-backed,
  no bolt pattern needed — see part 1 below).

## Parts

### 1. Base plate — `models/base_plate.scad`

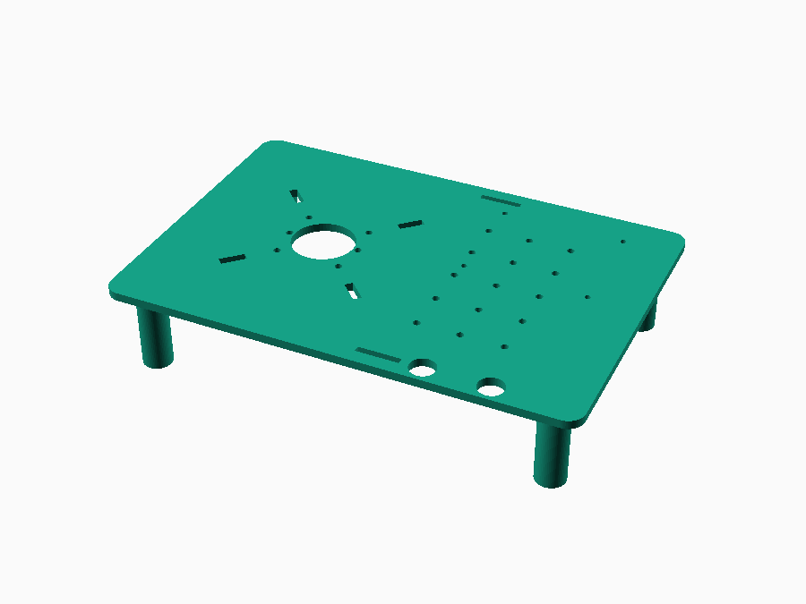
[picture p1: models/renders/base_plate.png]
base plate render


The stationary bottom of the scanner: bearing's fixed leaf, motor
(hanging underneath, shaft through the center bore), electronics, buttons,
battery straps, tripod mount.

| Dimension | Value | Notes |
|---|---|---|
| Overall | 220 × 150 × 4 mm | rounded corners, r=8mm |
| Center bore | ⌀30 mm | motor shaft + wiring pass-through |
| Bearing mounting | 4× slots, 4×12mm, on ⌀85mm bolt circle at 45/135/225/315° | **slots, not holes** — tolerant of your bearing's exact hole spacing; transfer-mark from the real part, see [BUILD.md](BUILD.md) |
| NEMA17 motor holes | 4× ⌀3.4mm (M3 clearance), 31.04×31.04mm square, centered on the bore | standard NEMA17 pattern |
| 28BYJ-48 motor holes | 2× ⌀3.4mm, 35mm apart, centered on the bore | both motor patterns are present simultaneously — use whichever matches your BOM tier |
| Feet | 4× ⌀14×40mm posts, corners | 40mm clears the NEMA17 body hanging underneath (see ARCHITECTURE.md) |
| Tripod mount | ⌀20mm boss, ⌀9.6mm pilot hole, underside | sized for a standard 1/4"-20 heat-set insert — **verify against the insert you buy**, they vary a mm or so by brand |
| Electronics grid | 3×5 array of ⌀3.4mm holes, 20mm pitch | generic mount — zip-tie or M3 standoff whatever you have. A half-size solderless breadboard (~85×55mm, BOM.md) sits here via its adhesive backing; it doesn't need to align with the grid holes, which stay free for the ULN2003 board, buttons, etc. A full-size breadboard (~165mm long) does *not* fit this zone next to the bearing — that's why BOM.md specifies half-size. |
| Pi 3 A+ mounting | 4× ⌀2.8mm on a 58×49mm rectangle, centered at (165, 108) | the standard Pi/HAT pattern, placed in the upper half of the electronics area so the strip below stays free for the breadboard + ULN2003. **Use M2.5 standoffs or small zip ties** — the Pi's own mounting holes are 2.75mm, too small for the M3 kit. The 65×56mm board overhangs the pattern by ~3.5mm per side; its left edge sits ~7mm into the battery-strap line (x≈120–140), so orient the Pi with its microSD slot facing away from the strap and route the strap over the plate, not over the board. |
| Button holes | 2× ⌀12mm | Sized for a panel-mount switch pushed through from below. This build instead uses pin-header button *modules* (BOM.md) which just sit in the open electronics area and don't need to pass through a hole — these two holes go unused by default, or repurpose them as wire/zip-tie pass-throughs. If you'd rather use bare panel-mount switches, they fit here as originally designed. |
| Battery strap slots | 2× 20×3mm slots | route a hook-and-loop strap or bungee through these to hold the power bank |

Print flat, no supports, PETG or PLA, 3-4 walls, 25% infill.

### 2. Rotating platter — `models/platter.scad`

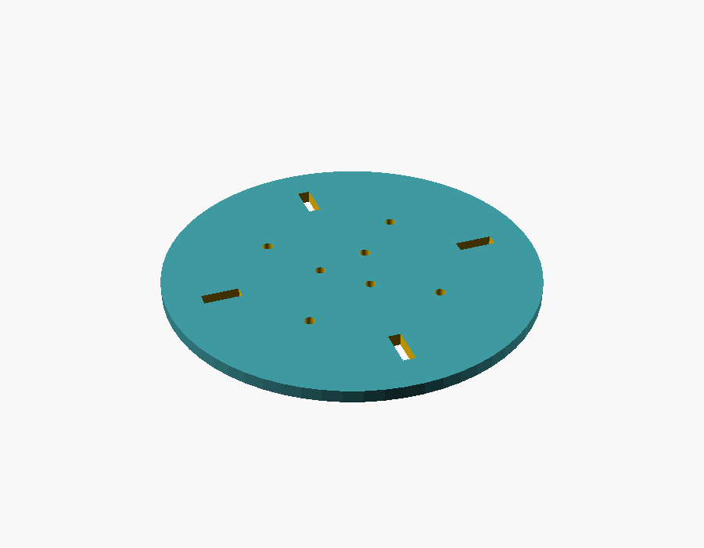
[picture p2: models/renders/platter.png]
platter render


The turntable top: bearing's rotating leaf, motor hub, mast all bolt here.

| Dimension | Value | Notes |
|---|---|---|
| Overall | ⌀120 × 4 mm disc | |
| Bearing mounting | same 4×12mm slots on ⌀85mm bolt circle as the base plate, 45/135/225/315° | **must match the base plate** — same bearing |
| Motor hub bolts | 3× ⌀3.4mm on ⌀20mm bolt circle, 90/210/330° | must match `motor_hub_*.scad` |
| Mast bolts | 4× ⌀3.4mm on ⌀60mm bolt circle, 0/90/180/270° | offset in both radius *and* angle from the bearing slots so nothing overlaps — must match `mast.scad` |

Print flat, no supports, PETG or PLA, 4+ walls, 30-40% infill (denser than
the base plate — this one carries the mast + sensor).

### 3. Mast — `models/mast.scad`

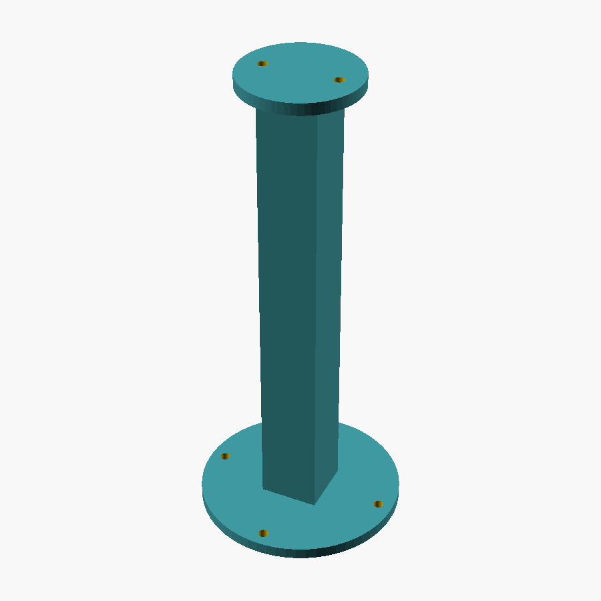
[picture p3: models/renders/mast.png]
mast render


| Dimension | Value | Notes |
|---|---|---|
| Post | 20×20mm square, 160mm tall | solid, not hollow — route the LiDAR's 4 wires externally, zip-tied along the post (see BUILD.md) |
| Bottom flange | ⌀70×4mm, 4× ⌀3.4mm holes on ⌀60mm bolt circle | bolts to the platter |
| Top flange | ⌀40×4mm, 2× ⌀3.4mm holes, 25mm apart | bolts to `lidar_mount.scad` |

160mm of height is enough to clear the base electronics for most of the
sensor's vertical field of view — some blind cone directly underneath is
unavoidable with this scan geometry regardless of mast height (see
[ARCHITECTURE.md § 8](ARCHITECTURE.md#8-known-limitations-inherent-to-this-scan-geometry-not-this-budget)).

Print standing up, no supports needed. PETG recommended over PLA — PLA
can slowly creep/lean under the sensor's small offset load, which would
show up as scan drift over time.

### 4. LiDAR mount bracket — `models/lidar_mount.scad`

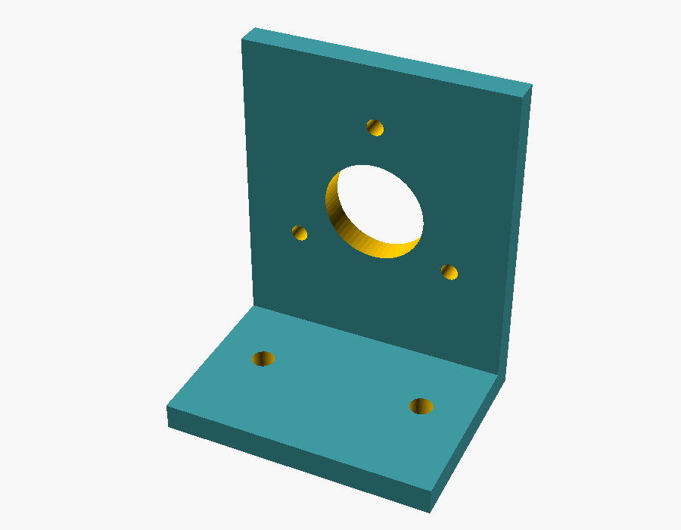
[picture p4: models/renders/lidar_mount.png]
lidar mount render


L-bracket holding the LD06/LD19 with its spin axis **horizontal** (mounting
face vertical) — see [ARCHITECTURE.md § 1](ARCHITECTURE.md#1-system-overview)
for why the sensor has to sit sideways, not flat like in a robot vacuum.

| Dimension | Value | Notes |
|---|---|---|
| Foot | 40×30×4mm, 2× ⌀3.4mm holes, 25mm apart | matches `mast.scad`'s top flange |
| Wall | 40mm wide × 45mm tall × 4mm thick, rising from the foot's back edge | |
| Sensor bolt circle | 3× ⌀2.5mm on **⌀27mm** bolt circle, 90/210/330° | **approximate — verify against your actual LD06/LD19 before printing.** This figure is a commonly-cited value, not measured from a datasheet in hand. If it's off, re-measure your unit's 3 mounting holes and edit `sensor_bolt_circle_d` in the .scad file before slicing. |
| Cable clearance | ⌀15mm, centered on the bolt circle | |

Print with the foot face-down, no supports (the wall is a straight
vertical extrusion, self-supporting).

**The sensor's physical offset from the mast's rotation axis is exactly
the `Y_OFFSET`/`Z_OFFSET` your software calibration needs** (see
`src/config.json` and [ARCHITECTURE.md](ARCHITECTURE.md)) — measure it on
the assembled bracket and start your calibration from that number rather
than guessing.

### 5. 28BYJ-48 motor hub — `models/motor_hub_uln2003.scad` (default build)

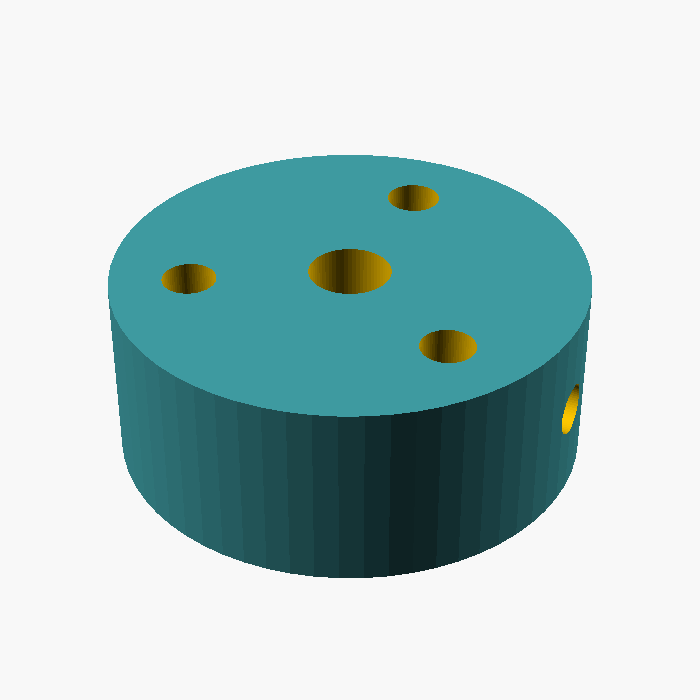
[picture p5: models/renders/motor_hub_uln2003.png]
uln2003 hub render


Clamps onto the 28BYJ-48's output shaft, bolts to the platter's underside.
This is the hub to print for the default, no-multimeter/no-soldering
build (BOM.md, BUILD.md).

| Dimension | Value | Notes |
|---|---|---|
| Hub | ⌀30 × 12mm | shorter than the NEMA17 hub below, matching the 28BYJ-48's shorter output shaft |
| Shaft bore | ⌀5.2mm | +0.2mm print-fit allowance over the ~5mm nominal shaft |
| Set screw | M3 radial, thread-formed into the print (or tap / threaded insert) | clamps onto the shaft's D-flat |
| Bolt pattern | 3× ⌀3.4mm on ⌀20mm bolt circle, 90/210/330° | must match `platter.scad` |

**Check your specific kit before printing**: many 28BYJ-48 motors ship
with a small plastic coupler/gear already pressed onto the output shaft.
Either remove it and bore this hub for the bare ~5mm D-shaft (the default
here), or measure that coupler's outer diameter and change `shaft_bore_d`
to clamp onto it instead.

### 6. NEMA17 motor hub — `models/motor_hub_nema17.scad` (optional upgrade, needs a multimeter)

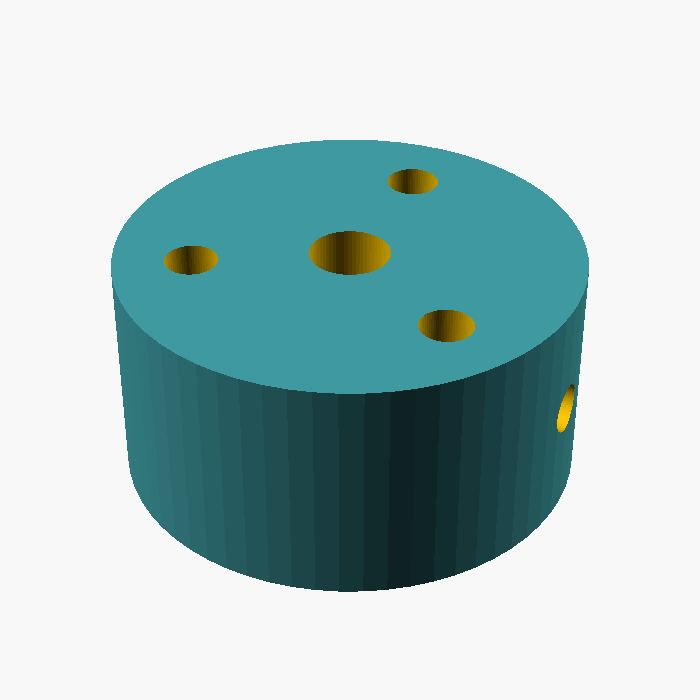
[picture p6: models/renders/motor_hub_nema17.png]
nema17 hub render


Not part of the default build — only print this if you're doing the
NEMA17 + A4988 upgrade (BOM.md, ARCHITECTURE.md § 4.2, BUILD.md's
appendix), which needs a multimeter to set up safely. Clamps onto the
NEMA17's 5mm D-shaft; same bolt pattern as the 28BYJ-48 hub above, just
taller (15mm) to match the NEMA17's longer shaft and carry more torque.

| Dimension | Value | Notes |
|---|---|---|
| Hub | ⌀30 × 15mm | (first draft was ⌀25mm — left only ~0.8mm wall around the bolt holes; bumped to 30mm for a real 3mm+ wall) |
| Shaft bore | ⌀5.2mm | NEMA17 shaft is 5mm nominal, +0.2mm print-fit allowance |
| Set screw | M3 radial, thread-formed into the print (or tap / threaded insert) | clamps onto the shaft's D-flat |
| Bolt pattern | 3× ⌀3.4mm on ⌀20mm bolt circle, 90/210/330° | must match `platter.scad` |

PETG strongly recommended for this part specifically — it's the highest
stress-concentration point in the whole mechanism.

## Print settings summary

| Part | Material | Infill | Supports |
|---|---|---|---|
| Base plate | PETG or PLA | 25% | No |
| Platter | PETG or PLA | 30-40% | No |
| Mast | PETG (PLA can creep) | 30% | No |
| LiDAR mount | PETG or PLA | 30% | No |
| Motor hub (28BYJ-48 or NEMA17) | PETG | 50%+ or solid | No |

All six parts print without supports as designed (flat plates, vertical
extrusions, no overhangs past 45°). None require a print bed larger than
220×150mm.

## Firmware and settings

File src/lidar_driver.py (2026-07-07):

"""
Serial driver for the LDRobot LD06 / LD19 2D LiDAR: reads the UART packet
stream, validates each packet's CRC8, decodes angle/distance/intensity,
converts to Cartesian, and buffers one LiDAR revolution at a time.

Adapted from PiLiDAR's lib/lidar_driver.py
(https://github.com/PiLiDAR/PiLiDAR), (c) Philip Gutjahr, CC BY-NC-SA 4.0
-- trimmed to drop the visualization hook and the Windows/MCU serial
branches (this build only ever talks to /dev/ttyS0 or a USB-serial
adapter on Linux).

Packet layout (48 bytes total, big-endian multi-byte fields), per the
LD06/LD19 development manual:
  byte 0      : start byte, always 0x54
  byte 1      : data-length byte (low 5 bits = 12 points/packet)
  bytes 2-3   : rotational speed (deg/s)
  bytes 4-5   : start angle (0.01 deg units)
  bytes 6-41  : 12 points x (2 bytes distance_mm, 1 byte intensity)
  bytes 42-43 : end angle (0.01 deg units)
  bytes 44-45 : timestamp (ms, wraps at 30000)
  byte 46     : CRC8 checksum over bytes 0-45
"""

import numpy as np
import serial

from platform_utils import init_serial


class Lidar:
    def __init__(self, config):
        self.sampling_rate = config.get("LIDAR", config.DEVICE, "SAMPLING_RATE")
        self.offset = config.get("LIDAR", config.DEVICE, "OFFSET")
        self.crc_table = config.crc_table
        self.verbose = False

        self.start_byte = config.get("LIDAR", "protocol", "start_byte")
        self.dlength_byte = config.get("LIDAR", "protocol", "dlength_byte")
        self.dlength = config.get("LIDAR", "protocol", "dlength")           # 12 points/packet
        self.package_len = config.get("LIDAR", "protocol", "package_len")  # 47 bytes after start+dlength byte... see read()
        self.deg2rad = np.pi / 180

        self.serial_connection = init_serial(port=config.PORT, baudrate=config.BAUDRATE)

        self.byte_array = bytearray()
        self.dtype = np.float32

        self.out_len = config.get("LIDAR", config.DEVICE, "OUT_LEN")  # packages per buffered revolution

        # preallocated per-packet scratch
        self.timestamp = 0
        self.speed = 0.0
        self.angle_package = np.zeros(self.dlength)
        self.distance_package = np.zeros(self.dlength)
        self.luminance_package = np.zeros(self.dlength)

        # preallocated per-revolution output
        self.out_i = 0
        self.points_2d = np.empty((self.out_len * self.dlength, 3), dtype=self.dtype)  # [x, y, intensity]

        self.z_angle = None          # set externally by the stepper each revolution
        self.z_angles = []           # recorded azimuth angle per revolution
        self.cartesian_list = []     # recorded points_2d snapshot per revolution

        # motor-speed PWM (LD06/LD19 have a "MOTOCTL" pin for closed-loop-ish speed control)
        pwm_cfg = config.get("LIDAR", "PWM")
        if pwm_cfg.get("ENABLE"):
            from platform_utils import init_pwm_Pi
            self.pwm = init_pwm_Pi(pwm_channel=pwm_cfg["CHANNEL"], frequency=pwm_cfg["FREQ"])
            self.pwm_coeffs = config.get("LIDAR", config.DEVICE, "PWM_COEFFS")
            self.target_speed = config.get("LIDAR", "TARGET_SPEED")
            self.pwm_dc = self.pwm_from_speed(self.target_speed)
            self.pwm.start(self.pwm_dc * 100)
        else:
            self.pwm = None

    def update_pwm_dc(self, pwm_dc):
        self.pwm_dc = max(0.0, min(1.0, pwm_dc))
        self.pwm.change_duty_cycle(self.pwm_dc * 100)
        return self.pwm_dc

    def update_speed(self, target_speed):
        self.target_speed = target_speed
        return self.update_pwm_dc(self.pwm_from_speed(target_speed))

    def speed_from_pwm(self, pwm):
        m, b = self.pwm_coeffs
        return m * pwm + b

    def pwm_from_speed(self, speed):
        m, b = self.pwm_coeffs
        return (speed - b) / m

    def close(self):
        if self.pwm is not None:
            self.pwm.stop()
        self.serial_connection.close()

    def read_loop(self, callback=None, max_packages=None):
        """Read packets until max_packages is hit (or forever if None).
        Every `out_len` packages, calls `callback()` (expected to advance
        the turntable one step and update self.z_angle), then snapshots
        the buffered revolution into cartesian_list/z_angles."""
        loop_count = 0
        while self.serial_connection.is_open and (max_packages is None or loop_count <= max_packages):
            try:
                if self.out_i == self.out_len:
                    if callback is not None:
                        callback()
                    self.z_angles.append(self.z_angle)
                    self.cartesian_list.append(np.copy(self.points_2d))
                    self.out_i = 0

                self._read_packet()
            except serial.SerialException:
                print("[ERROR] SerialException, stopping read loop.")
                break

            self.out_i += 1
            loop_count += 1

    def _read_packet(self):
        while self.serial_connection.is_open:
            data_byte = self.serial_connection.read()
            if data_byte == self.start_byte:
                next_byte = self.serial_connection.read()
                if next_byte == self.dlength_byte:
                    self.byte_array = self.serial_connection.read(self.package_len - 2)
                    self.byte_array = self.start_byte + self.dlength_byte + self.byte_array
                    break
                continue

        if len(self.byte_array) != self.package_len:
            if self.verbose:
                print("[WARNING] incomplete package:", self.byte_array)
            self.byte_array = bytearray()
            return

        if not self._check_crc8(self.byte_array):
            if self.verbose:
                print("[WARNING] CRC mismatch, dropping package")
            self.byte_array = bytearray()
            return

        self._decode(self.byte_array)
        x, y = self.polar2cartesian(self.angle_package, self.distance_package, self.offset)
        points_package = np.column_stack((x, y, self.luminance_package)).astype(self.dtype)

        self.points_2d[self.out_i * self.dlength:(self.out_i + 1) * self.dlength] = points_package
        self.byte_array = bytearray()

    def _decode(self, byte_array):
        self.speed = int.from_bytes(byte_array[2:4][::-1], "big") / 360  # rev/s
        fsa = float(int.from_bytes(byte_array[4:6][::-1], "big")) / 100  # start angle, deg
        lsa = float(int.from_bytes(byte_array[42:44][::-1], "big")) / 100  # end angle, deg
        self.timestamp = int.from_bytes(byte_array[44:46][::-1], "big")

        angle_step = ((lsa - fsa) if lsa - fsa > 0 else (lsa + 360 - fsa)) / (self.dlength - 1)

        for i, byte_i in enumerate(range(0, 3 * self.dlength, 3)):
            self.angle_package[i] = ((angle_step * i + fsa) % 360) * self.deg2rad
            self.distance_package[i] = int.from_bytes(byte_array[6 + byte_i:8 + byte_i][::-1], "big")  # mm
            self.luminance_package[i] = byte_array[8 + byte_i]

    @staticmethod
    def polar2cartesian(angles, distances, offset):
        angles = np.asarray(angles) + offset
        x = distances * -np.cos(angles)
        y = distances * np.sin(angles)
        return x, y

    def _check_crc8(self, data):
        payload, crc = data[:-1], data[-1]
        calc = 0
        for byte in payload:
            calc = self.crc_table[(calc ^ byte) & 0xFF]
        return calc == crc


if __name__ == "__main__":
    # quick bench test: prints live rotation speed for a few seconds
    import time
    from config import Config

    config = Config()
    config.init(scan_id="_bench")
    lidar = Lidar(config)

    print("Reading for 3s (Ctrl+C to stop early)...")
    t0 = time.time()
    try:
        while time.time() - t0 < 3:
            lidar._read_packet()
            if lidar.timestamp % 500 < 5:
                print(f"speed: {lidar.speed:.2f} rev/s")
    finally:
        lidar.close()

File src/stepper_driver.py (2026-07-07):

"""
Turntable stepper control. Two driver classes sharing one interface
(move_steps / move_angle / move_to_angle / get_current_angle / close) so
scan.py doesn't care which motor tier is installed -- see
ARCHITECTURE.md section 4 for the wiring of each.

`Stepper(config)` is a factory that returns the right class based on
config.json's STEPPER.DRIVER field ("A4988" or "ULN2003").

The A4988 class is adapted from PiLiDAR's lib/a4988_driver.py
(https://github.com/PiLiDAR/PiLiDAR), (c) Philip Gutjahr, CC BY-NC-SA 4.0.
The ULN2003 class is new (28BYJ-48 half-step sequencing is standard,
publicly-documented hardware behavior, not project-specific code).
"""

from time import sleep

import RPi.GPIO as GPIO


def Stepper(config):
    driver = config.get("STEPPER", "DRIVER")
    if driver == "A4988":
        return A4988(config.get("STEPPER", "pins", "DIR_PIN"),
                     config.get("STEPPER", "pins", "STEP_PIN"),
                     config.get("STEPPER", "pins", "MS_PINS"),
                     delay=config.get("STEPPER", "STEP_DELAY"),
                     step_angle=config.get("STEPPER", "STEP_ANGLE"),
                     microsteps=config.get("STEPPER", "MICROSTEPS"),
                     gear_ratio=config.get("STEPPER", "GEAR_RATIO"))
    if driver == "ULN2003":
        return ULN2003(config.get("STEPPER", "uln2003_pins"),
                        delay=config.get("STEPPER", "ULN2003_STEP_DELAY"),
                        steps_per_rev=config.get("STEPPER", "ULN2003_STEPS_PER_REV"),
                        gear_ratio=config.get("STEPPER", "GEAR_RATIO"))
    raise ValueError(f"Unknown STEPPER.DRIVER: {driver!r} (expected 'A4988' or 'ULN2003')")


class A4988:
    """NEMA17 via an A4988 microstepping driver (Recommended tier)."""

    def __init__(self, dir_pin, step_pin, ms_pins,
                 delay=0.0005, step_angle=1.8, microsteps=16,
                 gear_ratio=1.0, verbose=False):
        GPIO.setwarnings(verbose)
        GPIO.setmode(GPIO.BCM)

        self.dir_pin = dir_pin
        self.step_pin = step_pin
        self.ms_pins = ms_pins
        GPIO.setup(self.dir_pin, GPIO.OUT)
        GPIO.setup(self.step_pin, GPIO.OUT)
        for pin in self.ms_pins:
            GPIO.setup(pin, GPIO.OUT)

        self.current_steps = 0
        self.step_angle = step_angle or (360 / 200)
        self.microsteps = microsteps
        self.gear_ratio = gear_ratio
        self.delay = delay

        step_modes = {1: (False, False, False),
                      2: (True, False, False),
                      4: (False, True, False),
                      8: (True, True, False),
                      16: (True, True, True)}
        if self.microsteps not in step_modes:
            raise ValueError(f"Unsupported microstep count: {microsteps} (A4988 supports 1/2/4/8/16)")
        for pin, state in zip(self.ms_pins, step_modes[self.microsteps]):
            GPIO.output(pin, state)

    def set_direction(self, direction):
        GPIO.output(self.dir_pin, direction)

    def get_steps_for_angle(self, angle):
        return int((angle / self.step_angle) * self.microsteps * self.gear_ratio)

    def get_angle_for_steps(self, steps):
        return (steps / (self.microsteps * self.gear_ratio)) * self.step_angle

    def step(self):
        GPIO.output(self.step_pin, True)
        sleep(0.0001)
        GPIO.output(self.step_pin, False)
        sleep(self.delay)

    def move_steps(self, steps):
        direction = steps < 0  # clockwise is positive
        steps = abs(int(steps))
        self.set_direction(direction)
        for _ in range(steps):
            self.step()
        self.current_steps += -steps if direction else steps

    def move_angle(self, angle):
        steps = self.get_steps_for_angle(abs(angle))
        self.move_steps(steps if angle >= 0 else -steps)
        return steps

    def move_to_angle(self, target_angle, mod=True):
        if mod:
            target_angle %= 360
        angle_difference = target_angle - self.get_current_angle()
        if angle_difference > 180:
            angle_difference -= 360
        elif angle_difference < -180:
            angle_difference += 360
        self.move_steps(self.get_steps_for_angle(angle_difference))

    def get_current_angle(self, mod=True):
        angle = self.current_steps / (self.microsteps * self.gear_ratio) * self.step_angle
        return angle % 360 if mod else angle

    def close(self):
        GPIO.cleanup(self.ms_pins)
        GPIO.cleanup(self.dir_pin)
        GPIO.cleanup(self.step_pin)


class ULN2003:
    """28BYJ-48 geared stepper via a ULN2003 darlington driver board
    (Budget tier). Uses the standard 8-phase half-step sequence."""

    HALF_STEP_SEQUENCE = (
        (1, 0, 0, 0),
        (1, 1, 0, 0),
        (0, 1, 0, 0),
        (0, 1, 1, 0),
        (0, 0, 1, 0),
        (0, 0, 1, 1),
        (0, 0, 0, 1),
        (1, 0, 0, 1),
    )

    def __init__(self, pins, delay=0.0015, steps_per_rev=4096, gear_ratio=1.0, verbose=False):
        GPIO.setwarnings(verbose)
        GPIO.setmode(GPIO.BCM)

        self.pins = pins
        for pin in self.pins:
            GPIO.setup(pin, GPIO.OUT)
            GPIO.output(pin, False)

        self.delay = delay  # 28BYJ-48 is slow -- needs a longer inter-step delay than a NEMA17
        self.steps_per_rev = steps_per_rev
        self.gear_ratio = gear_ratio
        self.microsteps = 1  # kept for interface parity with A4988 (steps_per_rev already includes gearing)
        self.step_angle = 360 / steps_per_rev

        self.current_steps = 0
        self._phase = 0

    def get_steps_for_angle(self, angle):
        return int((angle / 360) * self.steps_per_rev * self.gear_ratio)

    def get_angle_for_steps(self, steps):
        return (steps / (self.steps_per_rev * self.gear_ratio)) * 360

    def _write_phase(self, phase_index):
        for pin, state in zip(self.pins, self.HALF_STEP_SEQUENCE[phase_index % 8]):
            GPIO.output(pin, bool(state))

    def move_steps(self, steps):
        direction = 1 if steps >= 0 else -1
        for _ in range(abs(int(steps))):
            self._phase += direction
            self._write_phase(self._phase)
            sleep(self.delay)
        self.current_steps += steps
        # de-energize coils between moves to save power and avoid overheating
        for pin in self.pins:
            GPIO.output(pin, False)

    def move_angle(self, angle):
        steps = self.get_steps_for_angle(abs(angle))
        self.move_steps(steps if angle >= 0 else -steps)
        return steps

    def move_to_angle(self, target_angle, mod=True):
        if mod:
            target_angle %= 360
        angle_difference = target_angle - self.get_current_angle()
        if angle_difference > 180:
            angle_difference -= 360
        elif angle_difference < -180:
            angle_difference += 360
        self.move_steps(self.get_steps_for_angle(angle_difference))
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

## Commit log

2026-07-07 Add BOM.md: parts list for budget DIY 360° LiDAR scanner
    Prices researched 2026-07-07. States the assumption explicitly: <=$100
    isn't reachable for an LD06/LD19-class stepper-driven scanner (the
    sensor alone runs $65-70), so this presents a $135 Budget build and a
    $150 Recommended build side by side, plus optional IMU/RGB upgrade
    paths and further cost-reduction levers for readers who want to push
    toward $100-120.
2026-07-07 Add ARCHITECTURE.md: pinout, motion system, and power budget
    Full BCM GPIO pinout (reused from PiLiDAR where the subsystem is
    unchanged), A4988 microstep/current-limit/sleep-reset wiring for the
    Recommended tier, ULN2003 wiring for the Budget tier, and a worst-case
    + typical-case power budget proving both tiers clear the 15-minute
    runtime requirement (4.8x and 7.0x margin respectively). Also explains
    the 180 degree scan geometry and why the design skips Open3D on-device.
    Reconciles BOM.md's runtime claims in the TL;DR and quality-difference
    section with the rigorous numbers computed here.
2026-07-07 Add src/: LiDAR capture, stepper control, PLY export, calibration
    Python codebase for the scanner, adapted from PiLiDAR where the
    CC BY-NC-SA 4.0 license permits (attributed per-file):
    - lidar_driver.py: LD06/LD19 UART capture, CRC8 validation, decode,
    motor-speed PWM control (with a software-PWM fallback if the
    hardware PWM overlay isn't enabled).
    - stepper_driver.py: A4988 (NEMA17, Recommended tier) and ULN2003
    (28BYJ-48, Budget tier) behind one interface, selected via
    config.json.
    - pointcloud.py: 2D-per-revolution -> merged XYZI point cloud and
    binary/ASCII PLY export, reimplemented in pure NumPy with no Open3D
    dependency (avoids a heavy native build on a 512MB Pi Zero 2 W).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
    [button_daemon.py, calibrate_mechanical.py, calibrate_pwm.py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]
2026-07-07 Add PRINTS.md and parametric OpenSCAD models for the 6 printed parts
    base_plate, platter, mast, lidar_mount, motor_hub_nema17, and
    motor_hub_uln2003 -- a from-scratch mechanical layout (not a port of
    PiLiDAR-Hardware's gearbox/enclosure CAD, which doesn't bolt up to this
    build's different motor/bearing choices, see BOM.md). Direct-drive
    motor instead of a planetary gearbox, a hardware lazy-susan bearing
    carries the load, and the battery is strapped on rather than enclosed
    so either BOM tier's power bank fits.
    Every part was actually rendered and checked (openscad --render,
    exported to STL, visually inspected), not just written and assumed
    correct. That process caught two real layout bugs be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
    [base_plate.scad, lidar_mount.scad, mast.scad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]
2026-07-07 Add BUILD.md: ordered assembly and test checklist
    Seven phases from printing through first accepted scan: print/prepare,
    mechanical assembly, wiring (per ARCHITECTURE.md's pinout), Raspberry Pi
    OS setup (overlays, udev rule, systemd service for the scan button),
    power-on checks done in dependency order (Pi alone, then LiDAR alone,
    then stepper alone, only then both together), calibration, and a first-
    scan acceptance checklist. Ends with a troubleshooting quick-reference
    table.
    Also fixes a real bug found while writing the systemd service section:
    button_daemon.py spawned scan.py via a literal "python3" string, which
    resolves through PATH and could hit the system interpreter instead of
    the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
    [button_daemon.py]
2026-07-07 Add root README.md as a navigation hub; reconcile BOM.md figures
    README ties the 5 deliverables together with an at-a-glance summary
    table. Also fixes an internal inconsistency in BOM.md's cost-reduction
    section: two different mentions of the achievable price range if using
    a used/pulled LiDAR sensor (~$100-115 vs ~$100-120) didn't actually
    match the arithmetic ($135 budget total - $67 sourced LiDAR + $25-45
    used LiDAR = $93-113); both now show the same, correctly-derived range.
2026-07-07 Redesign around no-soldering/no-multimeter constraint, raise cap to $175
    The user can't solder and doesn't have a multimeter, which the original
    two-tier design leaned on heavily: A4988's current-limit trimpot and the
    NEMA17 upgrade's boost-converter voltage trim both require a multimeter
    to set safely, and perfboard wiring assumes a soldering iron.
    Changes:
    - 28BYJ-48 + ULN2003 is now the single default build, not one of two
    tiers. Its ULN2003 driver just switches GPIO signals to the motor
    coils directly -- no current limit to set, so no multimeter needed.
    Running natively at 5V also removes the boost converter entirely,
    collapsing the whole system onto one 5V rail.
    - Wiring is now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
    [config.py, stepper_driver.py]
2026-07-07 Switch BOM to 100% Amazon sourcing, add Parts.md shopping list
    LiDAR now sourced from Amazon (~$90, WayPonDEV FHL-LD19 / Waveshare
    D300 listings) instead of the cheaper overseas sunsky-online option,
    trading ~$23 for Prime shipping and Amazon's return policy -- worth it
    specifically because a DOA sensor is hard to diagnose without a
    multimeter and much easier to just exchange. New total: $173 of the
    $175 cap (was $157), with only $2 of headroom left, mostly consumed by
    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
2026-07-07 Add Parts.md shopping list, update README for all-Amazon $173 total
    Parts.md is a plain name/price/link shopping list with no explanation,
    split out of BOM.md's fuller prose per request. README.md's summary
    table and doc list updated to match (new $173 total, Amazon-only
    sourcing, link to Parts.md).
2026-07-08 Replace out-of-stock lazy-susan bearing listing with in-stock alternates
    The FKG 4-inch bearing listing went out of stock. Swapped both BOM.md
    and Parts.md to a currently-available 2-pack listing, with single and
    8-pack alternates plus a generic Amazon search link as fallback, and
    noted explicitly that this is a commodity part -- any 4-inch square
    lazy-susan bearing works, which is exactly why the printed plates use
    slots + transfer-marking instead of assuming one brand's hole pattern.
    Price unchanged ($9), total stays $173.
2026-07-12 Document assumed-on-hand items: micro-USB power cable, SD access, straps
    Answering "will I need any more wires or electronics?" honestly exposed
    one real omission: the Pi Zero 2 W is powered via micro-USB (not
    USB-C), and no micro-USB cable was in the parts list -- the build
    implicitly assumed one from an old phone/gadget. Both BOM.md and
    Parts.md now have an explicit "assumed already on hand, check before
    ordering" section covering that cable, SD-card access for the one-time
    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
2026-07-13 Retarget build to Raspberry Pi 3 Model A+ across all docs and designs
    - BOM/Parts: swap Pi Zero 2 WH ($15) for Pi 3 A+ (~$30 street); total
    $188 new or $158 with an on-hand Pi, with the $175-cap tradeoff
    documented instead of hidden
    - ARCHITECTURE: rewrite compute section for the 3 A+ (1.4 GHz, dual-band
    Wi-Fi, factory-soldered header), recompute power budget at its higher
    draw (worst-case floor 210 -> 153 min, still 10.2x the requirement)
    - BUILD: add enable_uart=1 (mini-UART is off by default on the 3 A+),
    Pi mounting step, under-voltage troubleshooting row
    - base_plate.scad: add the standard 58x49mm Pi 3 A+ hole pattern
    (2.8mm, M2.5/zip-tie) in the electronics area; re-rendere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
    [base_plate.scad]
